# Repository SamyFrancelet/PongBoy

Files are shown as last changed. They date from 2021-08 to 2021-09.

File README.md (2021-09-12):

# PongBoy
 PongBoy is a simple handeld console, made with a 8-bit micro-controller

## Where is the report ?
 The report can be found on 0000_Docs/0004_Report/

## Where is the Schematic and PCB
 Everything Hardware related is located under 0300_Hardware

## Where is the software programmed for this project ?
 The software here is called firmware, and can be found under 0500_Firmware

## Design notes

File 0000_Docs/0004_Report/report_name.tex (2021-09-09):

\documentclass[11pt,titlepage]{report}
\usepackage{Preamble}

\begin{document}

\begin{titlepage}
	\newgeometry{margin=3cm}
	\centering
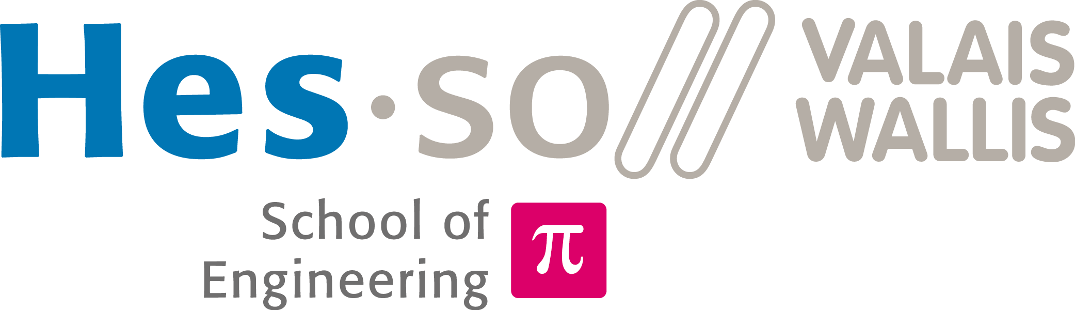
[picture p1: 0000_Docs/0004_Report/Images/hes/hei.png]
    \\[1cm] 	% University Logo
    \textsc{\LARGE Haute école d'ingénieur du Valais}\\ \vspace{\fill}
    \textbf{\textsc{\fontsize{35}{35}\selectfont Report Name}}\\ \vspace{\fill}
	\textsc{\LARGE Course name}\\[0.4cm]
	\rule{\linewidth}{0.2 mm} \\[0.5 cm]
	Author Name \\
	\today
\end{titlepage}
\restoregeometry

\tableofcontents

\chapter{Introduction}
\input{1-Introduction}

\chapter{Méthodes}
\input{2-Methods}

\chapter{Résultats}
\input{3-Results}

\chapter{Discussions}
\input{4-Discussion}

\chapter{Conclusion}
\input{5-Conclusion}

\end{document}

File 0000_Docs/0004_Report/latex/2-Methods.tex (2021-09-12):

\section{Développement Hardware}
L'architecture du Hardware se présente ainsi :
\begin{figure}[H]
  \centering
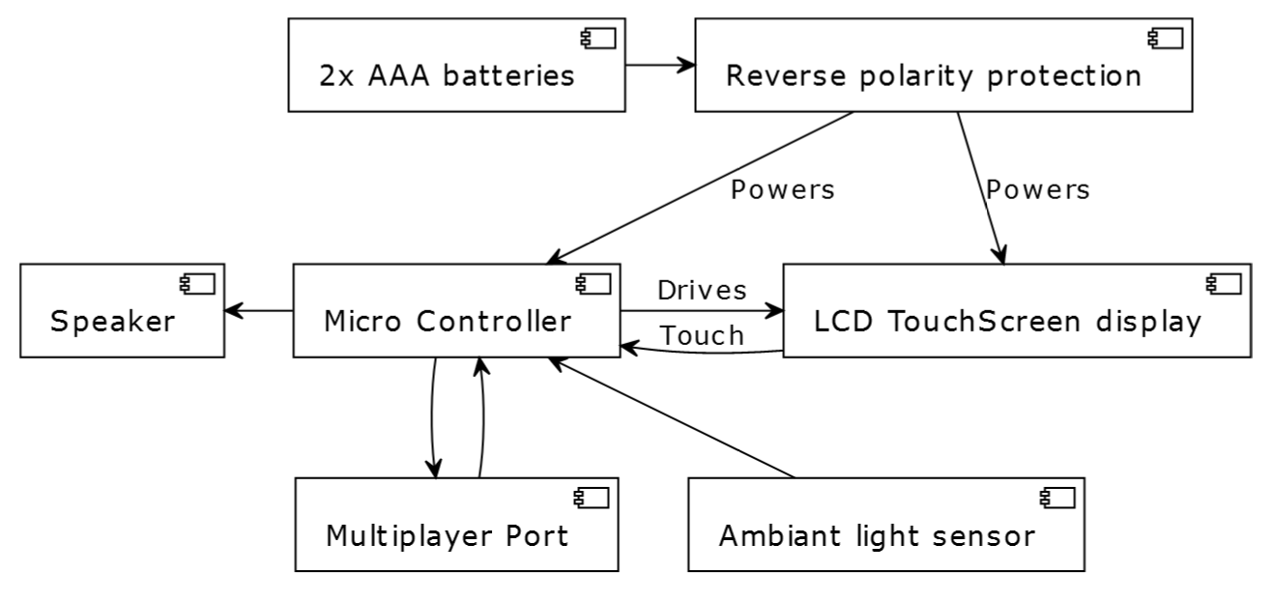
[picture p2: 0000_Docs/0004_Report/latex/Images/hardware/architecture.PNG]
  
  \caption{Architecture hardware de PongBoy}
  \label{hard_arc}
\end{figure}
Le circuit est alimenté par 2 piles AAA, et est protégé contre l'inversion
de polarité. Le micro controlleur commande et récupère des infos de l'écran,
de l'haut-parleur, du capteur de luminosité ambiante, et du port multi-joueur.
\newpage

\subsection{Alimentation}
\begin{figure}[H]
  \centering
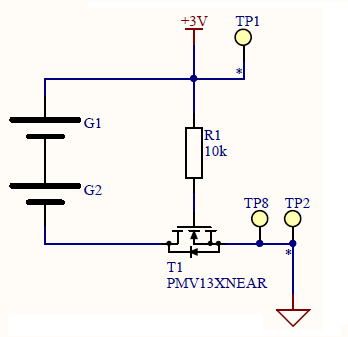
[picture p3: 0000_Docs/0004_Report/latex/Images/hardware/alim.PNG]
  
  \caption{Alimentation avec protection contre polarité inverse}
  \label{hard_pow}
\end{figure}
La protection d'inversion de polarité est un simple N-MOS qui déconnecte
la masse si la tension est inversée. Cette solution est un dérivé de la méthode
bien connue du P-MOS sur le VCC. Le P-MOS est souvent plus cher et moins
efficace que le N-MOS, ce qui est un problème sur notre circuit basse
consommation.
\newpage

\subsection{Micro Controlleur}
\begin{figure}[H]
  \centering
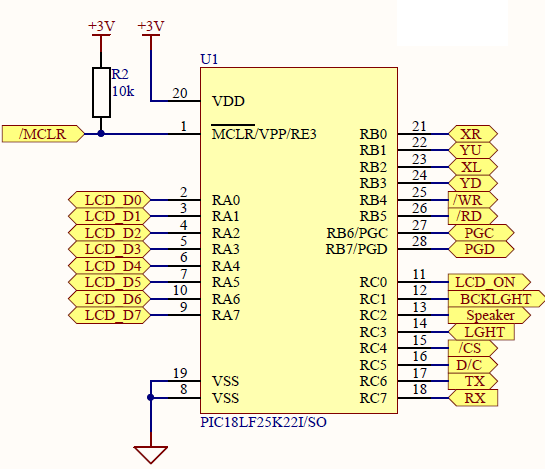
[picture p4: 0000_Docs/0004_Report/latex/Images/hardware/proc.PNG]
  
  \caption{Micro controlleur PIC18LF25K22 avec attribution des GPIO}
  \label{hard_proc}
\end{figure}
Le micro controlleur utilisé est plutôt limité en GPIO, seulement 3 PORT sont
disponibles, mais 3 PORT complet.
Le bus parallèle de l'écran LCD est entièrement attribué au PORTA.
Les 4 résistances de la dalle tactile sont disposée sur le PORTB, sur les pins
0 à 3, choisies pour leur capacités pull-up, d'interruption externe,
et de mesure analogique.
Le contrôle du rétroéclairage (BCKLGHT) est sur un GPIO avec capacité PWM.
PGC, PGD, TX, RX sont préassignée. Le reste n'a pas besoin de capacité
spécifique.

\begin{figure}[H]
  \centering
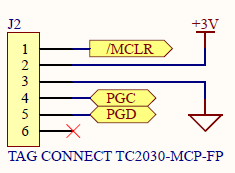
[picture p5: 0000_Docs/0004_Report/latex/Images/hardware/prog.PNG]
  
  \caption{Connecteur de programmation du PIC18LF25K22}
  \label{hard_prog}
\end{figure}
Le connecteur de programmation est un connecteur TagConnect. Le layout
du connecteur est celui du PicKit3.
\newpage

\subsection{Écran résistif tactile LCD}
\begin{figure}[H]
  \centering
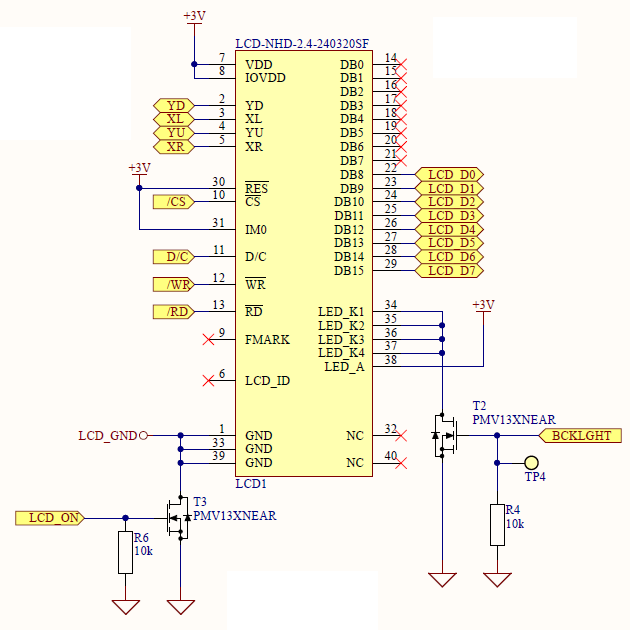
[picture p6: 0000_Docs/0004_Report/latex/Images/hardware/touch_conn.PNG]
  
  \caption{Connecteur de l'écran tacticle LCD}
  \label{hard_lcd}
\end{figure}
Des MOSFET sont présent pour couper l'alimentation de l'écran.
Étant donné que les MOSFET coupent la masse, il faut s'assurer qu'aucune
des pins de l'écran ne soit à la masse lorsqu'on coupe l'alimentation.
Si une pin se retrouve à la masse, un phénomène appelé \emph{Puit de courant}
se produit, et l'écran arrive à s'alimenter avec cette pin.

Pour ce qui est de la détection et mesure de la pression tactile, le principe
suivant sera utilisé sur les pins XR, XL, YU, YD :
\begin{figure}[H]
  \centering
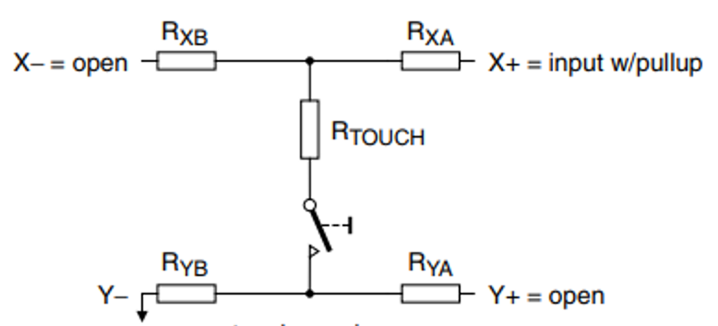
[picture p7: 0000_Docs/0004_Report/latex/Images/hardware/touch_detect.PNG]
  
  \caption{Détection de la pression tactile}
  \label{hard_touchDetect}
\end{figure}
Pour détecter la pression, on se sert de la dalle tactile comme d'un bouton
poussoir, qui va tirer une pin à la masse. Cela requiert donc une pull-up.

\begin{figure}[H]
  \centering
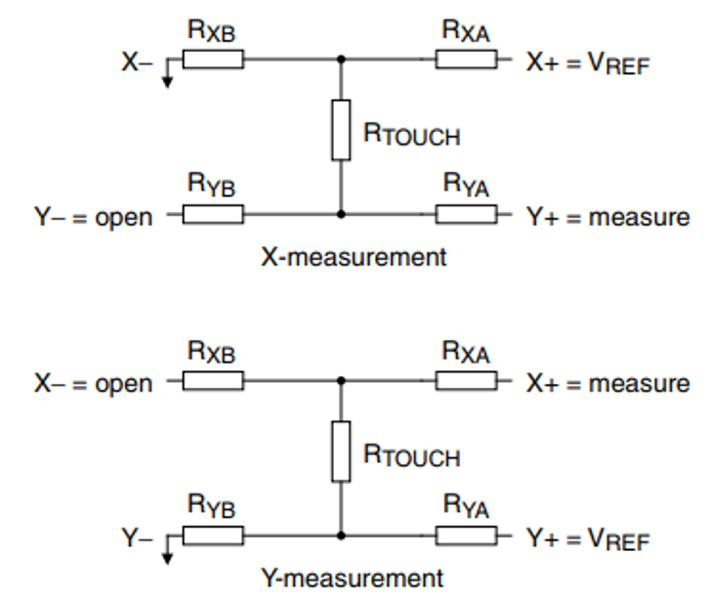
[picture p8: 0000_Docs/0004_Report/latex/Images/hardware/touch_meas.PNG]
  
  \caption{Mesure de la position de la pression tactile}
  \label{hard_touchMeas}
\end{figure}
Pour mesurer la position de la pression, on se sert du pont présent entre
le X et le Y pour faire la mesure. Ainsi, pour mesurer la position en X, nous
mesurons une des pins Y, et trouvons donc la tension du pont-diviseur X.
Et vice-versa pour la position Y.

\subsection{Périphériques}
\subsubsection{Haut-parleur}
\begin{figure}[H]
  \centering
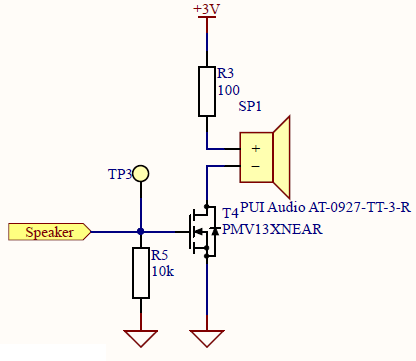
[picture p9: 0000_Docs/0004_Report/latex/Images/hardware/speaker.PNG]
  
  \caption{Haut-parleur avec MOSFET}
  \label{hard_speaker}
\end{figure}
Le haut-parleur est piloté avec un MOSFET, pour éviter de faire passer du
dans le micro controlleur. Il s'agit d'un haut-parleur inductif, il n'est
donc pas nécessaire d'ajouter de diode ou autre composant pour le fonctionnement
lorsque le MOSFET coupe le circuit.

\subsubsection{Capteur de luminosité ambiante}
\begin{figure}[H]
  \centering
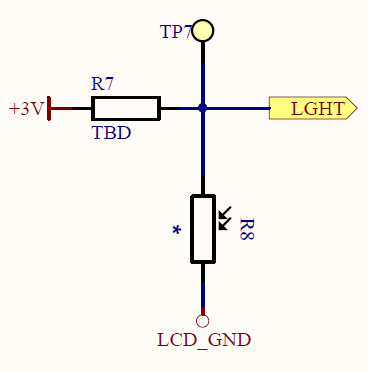
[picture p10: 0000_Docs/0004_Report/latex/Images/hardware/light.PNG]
  
  \caption{Mesure de la lumière ambiante}
  \label{hard_light}
\end{figure}
La mesure de lumière ambiante est réalisée avec une \emph{Light dependant
resistor}. La résistance varie en fonction de la lumière, et cette variation
est mesurée avec un pont-diviseur de tension.
Cette fonctionnalité n'est pour le moment pas du tout implémentée.

\subsubsection{Port multi-joueur}
\begin{figure}[H]
  \centering
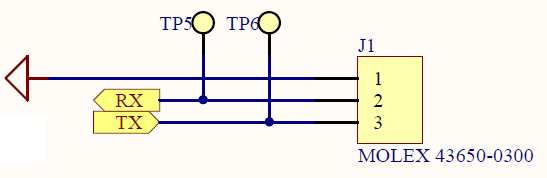
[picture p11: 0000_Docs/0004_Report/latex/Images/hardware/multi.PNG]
  
  \caption{Connecteur de communication pour mode multi-joueur}
  \label{hard_multi}
\end{figure}
Un connecteur 3-MOLEX a été choisi, pour avoir une communication full-duplex,
et transmettre une masse commune.
Cette fonctionnalité n'est pour le moment pas du tout implémentée.
\newpage

\section{Boitier mécanique}
\begin{figure}[H]
  \centering
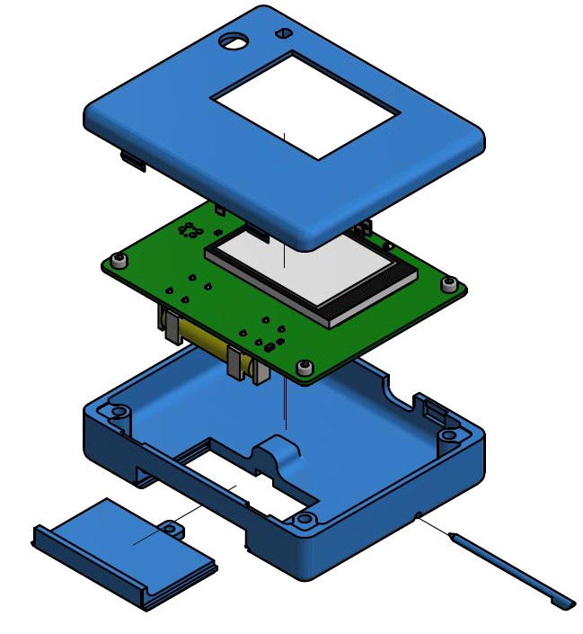
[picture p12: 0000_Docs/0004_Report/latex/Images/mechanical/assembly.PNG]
  
  \caption{Vue éclatée du boîtier complet}
  \label{mech_assembly}
\end{figure}
Le boîtier est composée de deux parties principales : La plaque inférieur,
surlaquelle le circuit imprimé viens se fixer. Et la plaque supérieur, qui
se \emph{clips} sur la plaque inférieur.
Le circuit imprimé est fixé à l'aide de vis M3, et d'inserts filtés.

Un point d'accès aux piles est présent, pour faciliter le changement de piles.
Un stylet a été pensé, pour éviter que l'utilisation du doigt pour le tactile
ne bloque la visibilité de l'écran. Il permet également une utilisation plus
précise du tactile. Le stylet est inspiré de celui d'une \emph{Nintendo DS}.
\begin{figure}[H]
  \centering
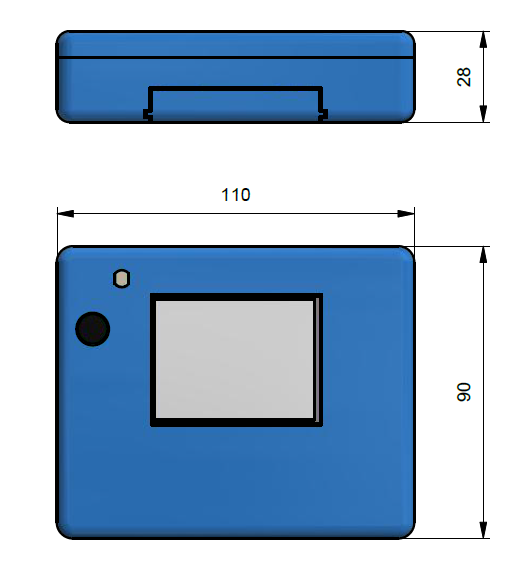
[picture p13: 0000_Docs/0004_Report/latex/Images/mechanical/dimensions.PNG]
  
  \caption{Dimensions d'encombrement du bôitier}
  \label{mech_dimensions}
\end{figure}
\newpage

\section{Développement Firmware}
\begin{figure}[H]
  \centering
  
  \caption{Architecture firmware}
  \label{firm_arc}
\end{figure}
Le firmware est découpé en plusieurs modules s'occupant chacun d'un élément
ou d'une partie du PongBoy spécifique :
\begin{itemize}
  \item le LCD driver s'occupe d'afficher sur l'écran, et de gérer le
  rétroéclairage
  \item TouchScreen s'occupe de détecter une pression sur l'écran, et
  de mesurer la position de cette pression pour la transmettre plus loin
  \item Display s'occupe de rafraîchir l'affichage toutes les $30ms$, il
  est informé des changement de menu vers sous-menu, ou vers le jeu
  \item PongBoy controller est une \emph{Factory}, il contient simplement
  tous les controlleurs de la console, comme Display ou Game Controller.
  Il s'occupe également de la mise en veille de la console.
  \item Menu Controller et Game Controller font le lien entre les
  commandes de l'utilisateur, et le menu ou jeu correspondant
  \item Les \emph{GameObjects} Ball et Paddle sont les balles et
  raquette du jeu Pong
\end{itemize}

Le liens entre tout ces modules est le gestionnaire d'évenement XF.
Chaque module peut envoyer un évenement dans la file d'attente de XF, ou
programmer un timer qui transmettera un évenement.
Cette file d'attente est vidée progressivement, et les évenements qui en sortent
sont retransmis à tous les modules, qui modifieront leur comportement selon
l'évenement. Un exemple simple : Le jeu se ferme lorsqu'il reçoit l'évenement
GameOver.

\subsection{TouchScreen}
\begin{figure}[H]
  \centering
  
  \caption{Diagramme d'activité du TouchScreen}
  \label{firm_touch}
\end{figure}
La détection de la pression et la méthode de mesure est détaillée au
point 2.1.3.
Le TouchScreen ne mesure que quand une pression est détectée. Les mesures
sont espacées entre elles à l'aide d'un timer.
À la fin de chaque conversion, le TouchScreen envoie un évenement signalant
une nouvelle mesure.
L'interruption externe du tactile permet de transmettre des évenement
\emph{Press} et \emph{Release}.
\newpage

\subsection{Mise en veille}
\begin{figure}[H]
  \centering
  
  \caption{Diagramme d'activité du PongBoy - fonction veille}
  \label{firm_sleep}
\end{figure}
La mise en veille est gérée avec un timer de XF de $20s$. À chaque
appui sur l'écran tactile, le timer est supprimé et un nouveau est relancé.
\newpage

\subsection{Contrôleurs}
\subsubsection{Pong Controller}
\begin{figure}[H]
  \centering
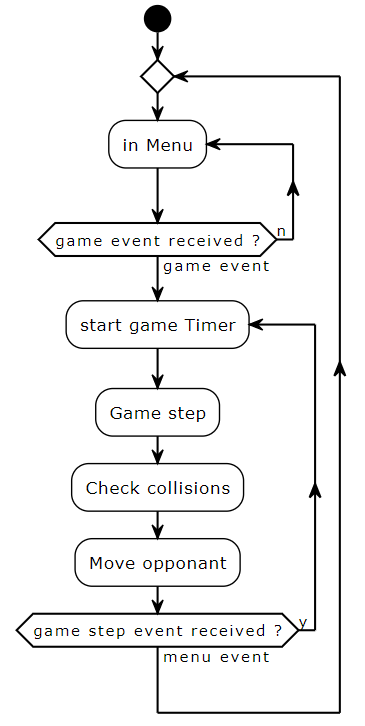
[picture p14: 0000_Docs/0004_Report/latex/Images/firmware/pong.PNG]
  
  \caption{Diagramme d'activité du Pong Controller}
  \label{firm_pong}
\end{figure}
Le contrôleur de jeu différencie deux états, en jeu et dans le menu.
Lorsqu'on est dans le menu, le jeu ne fais rien.
Lorsqu'on est en jeu, un timer est lancé pour gérer la physique du jeu.
L'affichage du jeu est découplé de ce contrôleur, l'afficheur sait simplement
qu'on est en jeu, et il affiche les objets du jeux sur l'écran toutes les $30ms$.

\subsubsection{Menu Controller}
Le contrôleur de menu fonctionne de manière similaire au pong, sans la partie
jeu. Il comprend des états de sous-menu.
\newpage

\subsection{Paddle}
\begin{figure}[H]
  \centering
  
  \caption{Diagramme d'activité du Paddle}
  \label{firm_paddle}
\end{figure}
La gestion du mouvement du Paddle joueur est découplée du contrôleur de jeu.
Le contrôleur de jeu transmet les évenements au Paddle.
Si une pression sur l'écran a été détectée, le Paddle va checker si la pression
est sur la partie du haut ou du bas de l'écran, et va modifier sa vitesse
en adéquation.

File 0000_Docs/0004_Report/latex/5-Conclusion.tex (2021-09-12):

\section{Bilan}
Le cahier des charges a été respecté dans son intégralité. Le mode veille
fonctionne consomme $9[\mu A]$.
Le gameplay est proche du vrai Pong, l'utilisation du stylet rend le gameplay
plus agréable qu'au doigt.
Le réglage du rétroéclairage fonctionne parfaitement, et permet aussi meilleure
autonomie.

\section{Points à corriger}
\begin{itemize}
  \item Sur le PCB v1.0, les signaux PGC et PGD ont été inversés sur le port
  de programmation.
  \item Sur le PCB v1.0 Les connecteurs de piles sont trop proches l'un de l'autre, du scotch.
  isolant a dû être placé pour éviter des courts-circuits.
  \item Sur le boîtier v2.1, les fixations de la plaque supérieur sont trop
  fragiles.
  \item Sur le boîtier v2.1, l'accès aux piles est trop étroit et rend
  le changement de pile avec les doigts très désagréable.
  \item Sur le boîtier v2.1, le stylet ne peut pas rentrer correctement dans
  le boîtier à cause de l'impression 3D imprécise.
  \item Les pull-downs présentent sur les Gate des MOSFET ne sont pas
  nécessaires. Le PIC18LF25K22, lorsqu'il part en veille, concerve
  l'état de ses entrées/sorties d'avant veille.
\end{itemize}

\section{Voies d'amélioration}
\begin{itemize}
  \item Ajout d'un joystick ou slider pour le contrôle du Paddle.
  \item Amélioration du menu du PongBoy, ajout d'informations visuelles pour
  l'utilisateur (par ex: le slider de luminosité n'a pas de légende).
  \item Ajout de plusieurs réglages dans le menu paramètres (par ex: choisir
  de jouer sur fond blanc plutôt que fond noir).
  \item Amélioration du gameplay (balle qui s'accélère durant la manche).
  \item Ajout d'un choix de difficulté de l'adversaire dans Pong.
  \item Implémentation du haut-parleur, ajout de feedback sonore dans le menu
  et dans le Pong.
  \item Implémentation du capteur de luminosité ambiante, et réglage automatique
  du rétroéclairage.
  \item Implémentation du mode multi-joueur.
\end{itemize}

\section{Signatures}
Samy Francelet

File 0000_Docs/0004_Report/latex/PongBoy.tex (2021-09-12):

\documentclass[11pt,titlepage]{report}
\usepackage{Preamble}

\begin{document}

\begin{titlepage}
	\newgeometry{margin=3cm}
	\centering
    \\[1cm] 	% University Logo
    \textsc{\LARGE Haute école d'ingénieur du Valais}\\ \vspace{\fill}
    \textbf{\textsc{\fontsize{35}{35}\selectfont PongBoy}}\\ \vspace{\fill}
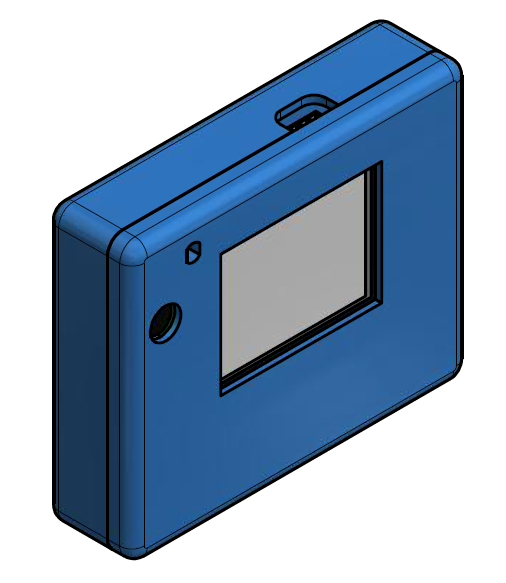
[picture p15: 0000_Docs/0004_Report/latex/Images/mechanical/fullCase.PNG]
		\\[2cm]
	\textsc{\LARGE Summer School 2}\\[0.4cm]
	\rule{\linewidth}{0.2 mm} \\[0.5 cm]
	Samy Francelet \\
	\today
\end{titlepage}
\restoregeometry

\tableofcontents

\chapter{Introduction}
\input{1-Introduction}

\chapter{Conception}
\input{2-Methods}

\chapter{Résultats et tests}
\input{3-Results}

%\chapter{Discussions}
%\input{4-Discussion}

\chapter{Conclusion}
\input{5-Conclusion}

\appendix
\chapter{Protocoles de test}
\includepdf[pages=-]{files/Test_protocols.pdf}

\end{document}

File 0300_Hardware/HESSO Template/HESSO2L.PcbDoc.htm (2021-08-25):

Reporting Options

# File in Previous Format

Date | : | 25.08.2021
Time | : | 13:53:03
Filename | : | C:\Users\samy.francele\Documents\PongBoy\0300_Hardware\HESSO Template\HESSO2L.PcbDoc

Version | Warning

This file was generated by an earlier version of the software

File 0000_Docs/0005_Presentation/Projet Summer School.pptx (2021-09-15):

## Projet Summer School PongBoy

Samy Francelet

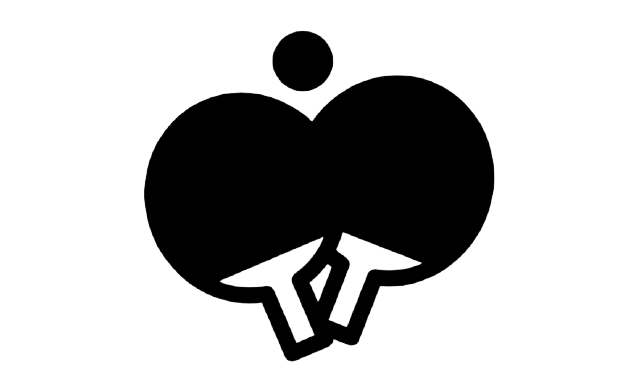
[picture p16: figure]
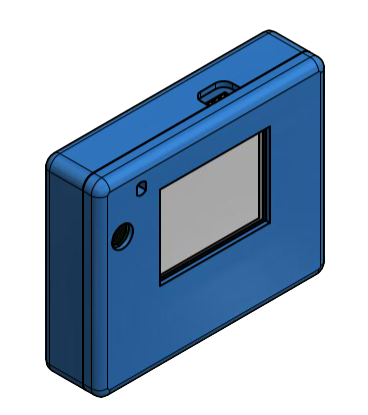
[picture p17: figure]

## Sommaire

Cahier des charges
Hardware
Mécanique
Firmware
Résultats
Bilan

## Cahier des charges

Basse consommation
Pile AAA
Écran tactile résistif
Pas de puce driver
Processeur : PIC18LF25K22
Nombre de GPIO limité
Console de jeu portable Pong
8 bits
Possibilités de calcul limitées
Basse consommation
3 semaines

## Hardware

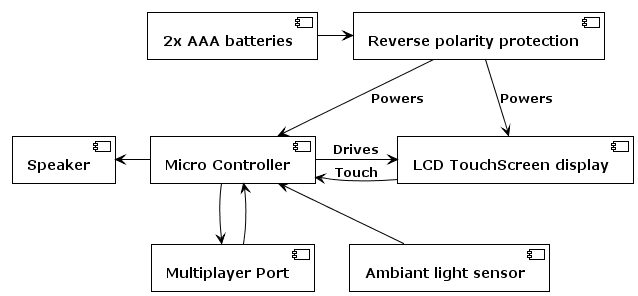
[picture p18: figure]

## Mécanique

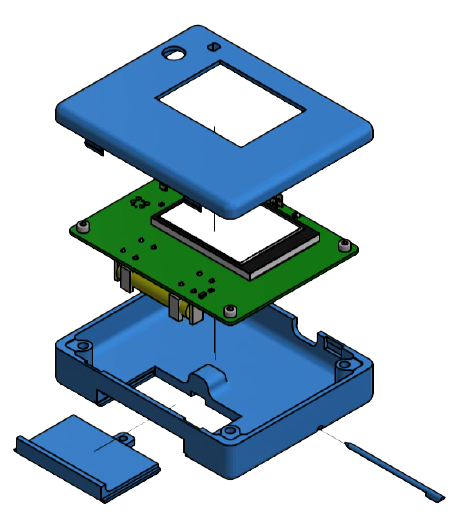
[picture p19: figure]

## Structure du Firmware

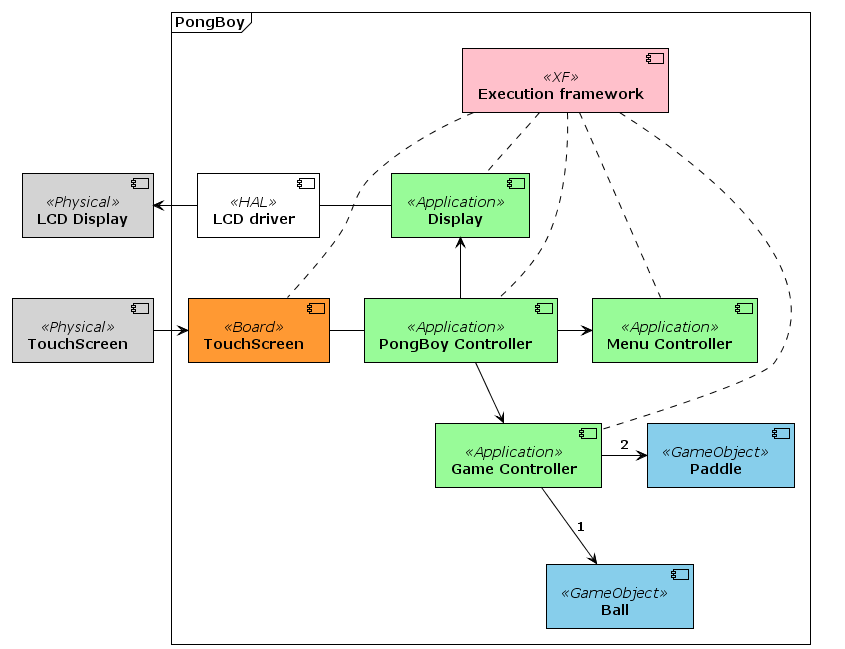
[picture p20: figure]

## Lecture du TouchScreen

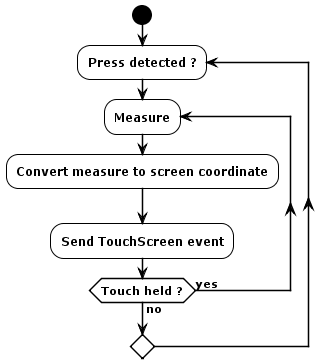
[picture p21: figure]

## Gestion de l’alimentation

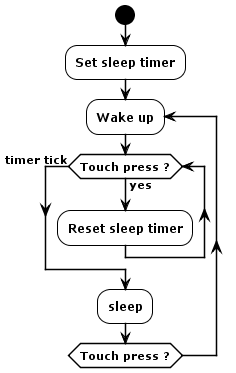
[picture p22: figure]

## Controlleur de jeu

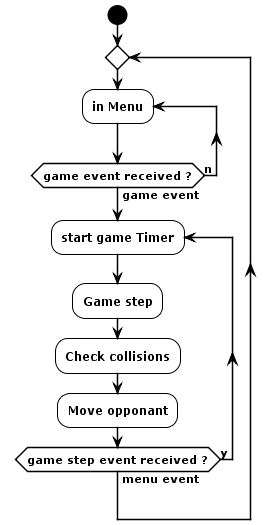
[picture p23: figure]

## Control du Paddle

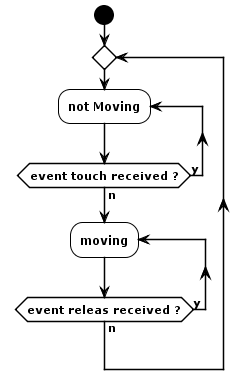
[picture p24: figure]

## Résultats

- Protection de l’inversion de polarité des piles
- Gestion de l’énergie fonctionnelle
- Gestion du rétroéclairage fonctionnelle
- Code réutilisable

## Résultats


## Bilan

Corrections :
Schématique et circuit imprimé
Voie d’améliorations :
Niveaux de difficulté
Joystick ou slider pour le contrôle
Haut-parleur
Détection de la lumière ambiante
Mode multijoueur
Accès des piles plus large
Cahier des charges respecté
Game Over
Menu plus complet
Fixation de la plaque du dessus plus solide

## Questions


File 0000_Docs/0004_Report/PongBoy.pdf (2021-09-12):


### HAUTE ÉCOLE D’INGÉNIEUR DU VALAIS

# PONGBOY


### SUMMER SCHOOL 2

Samy Francelet
12 septembre 2021

# Table des matières

1 Introduction | 2
2 Conception | 3
3 Résultats et tests | 15
4 Conclusion | 17
A Protocoles de test | 18

# Chapitre 1

# Introduction

## 1.1 Contexte

Ce projet a été réalisé dans le cadre du cours Summer School 2 - Infotronic de la Haute école d’ingénieur du Valais. Ce cours de 3 semaines se passe à la fin de l’été, avant la reprise de septembre. Il a pour but de mettre en pratique les compétences acquises durant la 2e année du bachelor. L’objectif du projet est de développer une console de jeu portable, avec écran tactile, permettant de jouer au jeu Pong.
Normalement, des équipes de 2 personnes sont formées, mais dû au fait que nous sommes un nombre impaire, je me suis retrouvé à développer le PongBoy seul.

## 1.2 Spécifications

— La console doit être alimentée par 2 piles AAA en série, et ainsi fonctionner en 3[V ].
— Une protection contre l’inversion de polarité des piles doit être présente.
— La console doit pouvoir être mise en veille ultra-basse-consommation, pour éviter de changer les piles AAA trop régulièrement.
— L’écran tactile résistif NHD-2.4-240320SF-CTXL-FTN1 doit être utilisé, et une interface tactile doit être implémentée.
— L’utilisation d’une puce driver pour l’écran tactile est prohibée, une librairie driver est fournie. — Le micro-controlleur PIC18LF25K22 doit être utilisé, au format SOIC, pour ses capacités d’ultrabasse-consommation.
— L’alimentation de l’écran LCD ainsi que de son rétro-éclairage doit pouvoir être coupée pour respecter la contrainte d’ultra-basse-consommation.

# Chapitre 2

# Conception

## 2.1 Développement Hardware

L’architecture du Hardware se présente ainsi :


FIGURE 2.1 – Architecture hardware de PongBoy

Le circuit est alimenté par 2 piles AAA, et est protégé contre l’inversion de polarité. Le micro controlleur commande et récupère des infos de l’écran, de l’haut-parleur, du capteur de luminosité ambiante, et du port multi-joueur.

Conception | PongBoy - Summer School 2

### 2.1.1 Alimentation


FIGURE 2.2 – Alimentation avec protection contre polarité inverse

La protection d’inversion de polarité est un simple N-MOS qui déconnecte la masse si la tension est inversée. Cette solution est un dérivé de la méthode bien connue du P-MOS sur le VCC. Le P-MOS est souvent plus cher et moins efficace que le N-MOS, ce qui est un problème sur notre circuit basse consommation.

### 2.1.2 Micro Controlleur


FIGURE 2.3 – Micro controlleur PIC18LF25K22 avec attribution des GPIO

Le micro controlleur utilisé est plutôt limité en GPIO, seulement 3 PORT sont disponibles, mais 3 PORT complet. Le bus parallèle de l’écran LCD est entièrement attribué au PORTA. Les 4 résistances de la dalle tactile sont disposée sur le PORTB, sur les pins 0 à 3, choisies pour leur capacités pull-up, d’interruption externe, et de mesure analogique. Le contrôle du rétroéclairage (BCKLGHT) est sur un GPIO avec capacité PWM. PGC, PGD, TX, RX sont préassignée. Le reste n’a pas besoin de capacité spécifique.


FIGURE 2.4 – Connecteur de programmation du PIC18LF25K22

Le connecteur de programmation est un connecteur TagConnect. Le layout du connecteur est celui du PicKit3.

### 2.1.3 Écran résistif tactile LCD


FIGURE 2.5 – Connecteur de l’écran tacticle LCD

Des MOSFET sont présent pour couper l’alimentation de l’écran. Étant donné que les MOSFET coupent la masse, il faut s’assurer qu’aucune des pins de l’écran ne soit à la masse lorsqu’on coupe l’alimentation. Si une pin se retrouve à la masse, un phénomène appelé Puit de courant se produit, et l’écran arrive à s’alimenter avec cette pin.
Pour ce qui est de la détection et mesure de la pression tactile, le principe suivant sera utilisé sur les pins XR, XL, YU, YD :


FIGURE 2.6 – Détection de la pression tactile

Pour détecter la pression, on se sert de la dalle tactile comme d’un bouton poussoir, qui va tirer une pin à la masse. Cela requiert donc une pull-up.


FIGURE 2.7 – Mesure de la position de la pression tactile

Pour mesurer la position de la pression, on se sert du pont présent entre le X et le Y pour faire la mesure. Ainsi, pour mesurer la position en X, nous mesurons une des pins Y, et trouvons donc la tension du pont-diviseur X. Et vice-versa pour la position Y.

### 2.1.4 Périphériques

Haut-parleur


FIGURE 2.8 – Haut-parleur avec MOSFET

Le haut-parleur est piloté avec un MOSFET, pour éviter de faire passer du dans le micro controlleur. Il s’agit d’un haut-parleur inductif, il n’est donc pas nécessaire d’ajouter de diode ou autre composant pour le fonctionnement lorsque le MOSFET coupe le circuit.

Capteur de luminosité ambiante


FIGURE 2.9 – Mesure de la lumière ambiante

La mesure de lumière ambiante est réalisée avec une Light dependant resistor. La résistance varie en fonction de la lumière, et cette variation est mesurée avec un pont-diviseur de tension. Cette fonctionnalité n’est pour le moment pas du tout implémentée.

Port multi-joueur


FIGURE 2.10 – Connecteur de communication pour mode multi-joueur

Un connecteur 3-MOLEX a été choisi, pour avoir une communication full-duplex, et transmettre une masse commune. Cette fonctionnalité n’est pour le moment pas du tout implémentée.

## 2.2 Boitier mécanique


FIGURE 2.11 – Vue éclatée du boîtier complet

Le boîtier est composée de deux parties principales : La plaque inférieur, surlaquelle le circuit imprimé viens se fixer. Et la plaque supérieur, qui se clips sur la plaque inférieur. Le circuit imprimé est fixé à l’aide de vis M3, et d’inserts filtés.
Un point d’accès aux piles est présent, pour faciliter le changement de piles. Un stylet a été pensé, pour éviter que l’utilisation du doigt pour le tactile ne bloque la visibilité de l’écran. Il permet également une utilisation plus précise du tactile. Le stylet est inspiré de celui d’une Nintendo DS.


FIGURE 2.12 – Dimensions d’encombrement du bôitier

## 2.3 Développement Firmware


FIGURE 2.13 – Architecture firmware

Le firmware est découpé en plusieurs modules s’occupant chacun d’un élément ou d’une partie du PongBoy spécifique :
— le LCD driver s’occupe d’afficher sur l’écran, et de gérer le rétroéclairage
— TouchScreen s’occupe de détecter une pression sur l’écran, et de mesurer la position de cette pression pour la transmettre plus loin
— Display s’occupe de rafraîchir l’affichage toutes les 30ms, il est informé des changement de menu vers sous-menu, ou vers le jeu
— PongBoy controller est une Factory, il contient simplement tous les controlleurs de la console, comme Display ou Game Controller. Il s’occupe également de la mise en veille de la console. — Menu Controller et Game Controller font le lien entre les commandes de l’utilisateur, et le menu ou jeu correspondant
— Les GameObjects Ball et Paddle sont les balles et raquette du jeu Pong
Le liens entre tout ces modules est le gestionnaire d’évenement XF. Chaque module peut envoyer un évenement dans la file d’attente de XF, ou programmer un timer qui transmettera un évenement. Cette file d’attente est vidée progressivement, et les évenements qui en sortent sont retransmis à tous les modules, qui modifieront leur comportement selon l’évenement. Un exemple simple : Le jeu se ferme lorsqu’il reçoit l’évenement GameOver.

### 2.3.1 TouchScreen


FIGURE 2.14 – Diagramme d’activité du TouchScreen

La détection de la pression et la méthode de mesure est détaillée au point 2.1.3. Le TouchScreen ne mesure que quand une pression est détectée. Les mesures sont espacées entre elles à l’aide d’un timer. À la fin de chaque conversion, le TouchScreen envoie un évenement signalant une nouvelle mesure. L’interruption externe du tactile permet de transmettre des évenement Press et Release.

### 2.3.2 Mise en veille


FIGURE 2.15 – Diagramme d’activité du PongBoy - fonction veille

La mise en veille est gérée avec un timer de XF de 20s. À chaque appui sur l’écran tactile, le timer est supprimé et un nouveau est relancé.

### 2.3.3 Contrôleurs

Pong Controller


FIGURE 2.16 – Diagramme d’activité du Pong Controller

Le contrôleur de jeu différencie deux états, en jeu et dans le menu. Lorsqu’on est dans le menu, le jeu ne fais rien. Lorsqu’on est en jeu, un timer est lancé pour gérer la physique du jeu. L’affichage du jeu est découplé de ce contrôleur, l’afficheur sait simplement qu’on est en jeu, et il affiche les objets du jeux sur l’écran toutes les 30ms.

Menu Controller

Le contrôleur de menu fonctionne de manière similaire au pong, sans la partie jeu. Il comprend des états de sous-menu.

### 2.3.4 Paddle


FIGURE 2.17 – Diagramme d’activité du Paddle

La gestion du mouvement du Paddle joueur est découplée du contrôleur de jeu. Le contrôleur de jeu transmet les évenements au Paddle. Si une pression sur l’écran a été détectée, le Paddle va checker si la pression est sur la partie du haut ou du bas de l’écran, et va modifier sa vitesse en adéquation.

# Chapitre 3

# Résultats et tests

## 3.1 Résultats


FIGURE 3.1 – Boîtier complet du PongBoy

Le cahier des charges est respecté. La jouabilité est correcte. Par manque de temps, et manque de ressources humaines, les fonctionnalités comme le haut-parleur, et le mode multi-joueur n’ont pas pu être implémentés.

Résultats et tests | PongBoy - Summer School 2

## 3.2 Test

De nombreux tests ont été réalisés pour vérifier la qualité du produit. Ces tests ont permis de détecter de nombreux problèmes, qui ont bien entendu été corrigés.


FIGURE 3.2 – Signaux de programmation PGC et PGD inversés

Par exemple, les signaux PGC et PGD du port de programmation ont été inversé dans la schématique, résultant en une impossibilité de programmer le processeur. Cela a été corrigé comme montré dans la figure 3.2
L’ensemble des tests réalisés durant ce projet sont disponibles en Annexe A.

# Chapitre 4

# Conclusion

## 4.1 Bilan

Le cahier des charges a été respecté dans son intégralité. Le mode veille fonctionne consomme 9[µA]. Le gameplay est proche du vrai Pong, l’utilisation du stylet rend le gameplay plus agréable qu’au doigt. Le réglage du rétroéclairage fonctionne parfaitement, et permet aussi meilleure autonomie.

## 4.2 Points à corriger

— Sur le PCB v1.0, les signaux PGC et PGD ont été inversés sur le port de programmation.
— Sur le PCB v1.0 Les connecteurs de piles sont trop proches l’un de l’autre, du scotch. isolant a dû être placé pour éviter des courts-circuits.
— Sur le boîtier v2.1, les fixations de la plaque supérieur sont trop fragiles.
— Sur le boîtier v2.1, l’accès aux piles est trop étroit et rend le changement de pile avec les doigts très désagréable.
— Sur le boîtier v2.1, le stylet ne peut pas rentrer correctement dans le boîtier à cause de l’impression 3D imprécise.
— Les pull-downs présentent sur les Gate des MOSFET ne sont pas nécessaires. Le PIC18LF25K22, lorsqu’il part en veille, concerve l’état de ses entrées/sorties d’avant veille.

## 4.3 Voies d’amélioration

— Ajout d’un joystick ou slider pour le contrôle du Paddle.
— Amélioration du menu du PongBoy, ajout d’informations visuelles pour l’utilisateur (par ex : le slider de luminosité n’a pas de légende).
— Ajout de plusieurs réglages dans le menu paramètres (par ex : choisir de jouer sur fond blanc plutôt que fond noir).
— Amélioration du gameplay (balle qui s’accélère durant la manche).
— Ajout d’un choix de difficulté de l’adversaire dans Pong.
— Implémentation du haut-parleur, ajout de feedback sonore dans le menu et dans le Pong.
— Implémentation du capteur de luminosité ambiante, et réglage automatique du rétroéclairage. — Implémentation du mode multi-joueur.

## 4.4 Signatures

Samy Francelet

# Annexe A

# Protocoles de test

Test ID | Hardware - 01
Description | Inspection des défauts de fabrication
Pattern | White Box
Test Description | Le PCB, juste après la fabrication et l'usinage, est inspecté à la loupe dans le but de rechercher d'éventuelle court circuit entre les pistes ou alors des pistes coupées qui aurait été rongée par l'acide
Personnel | Samy Francelet
Results | 2 pistes coupées : PGC et PGD
Conclusions | Le cuivre de la face supérieur a été plus mangé par l'acide, les pistes fines du port de programmation en ont souffert
Measures | Un morceau de fil conducteur a été soudé par-dessus la piste
Test ID | Hardware - 02
Description | Ce test permet de vérifier si le PCB n'a pas de court-circuit
Pattern | Smoke test
Test Description | Le PCB assemblé complet va être inspecté à la loupe, puis alimenté en 3V, avec une limitation de courant <150mA pour éviter de faire de trop gros dégats en cas de court-circuit.
Personnel | Samy Francelet
Results | Pas de court-circuit observé. Le courant est <10mA.
Conclusions | Ce courant correspond à la consommation du PIC n'étant pas encore programmé.
Measures | Le test est réussi.
Test ID | Hardware - 03
Description | Ce test permet de vérifier la protection contre l'inversion de polarité
Pattern | Smoke test
Test Description | On inverse la polarité de l'alimentation afin de voir si notre protection fonctionne correctement
Personnel | Samy Francelet
Results | Pas d'échauffement de composant. Pas de courant
Conclusions | La protection d'alimentation fonctionne correctement
Measures | Le test est réussi.

Test ID | Firmware - 01
Description | Programmabilité du micro contrôleur
Pattern | White Box
Test Description | On lance MPLAB puis on crée un nouveau projet avec le bon compilateur (XC8) et le bon PIC (18LF25k22). Le PCB vient se connecter avec le connecteur de programmation sur l'ordinateur. Une première compilation et programmation est lancée. Si le programme s'arrête avec une erreur, on débranche le Pickit3 et on cherche la faute. Sinon, le test prend fin.
Personnel | Samy Francelet
Results | MPLAB ne reconnait pas le micro contrôleur
Conclusions | Les pins PGC et PGD sont inversées
Measures | Les deux pistes sont coupées et deux fils sont utilisés à la place
Test ID | Firmware - 02
Description | Changement de couleur de fond d'écran
Pattern | White Box
Test Description | Vérifie que la commande tactile fonctionne, et que la communicaiton avec l'écran fonctionne
Personnel | Samy Francelet
Results | Fonctionnel
Conclusions | Le test est reussi

Measures

Test ID | Firmware - 03
Description | Balle qui rebondit contre les parois de l'écran
Pattern | White Box
Test Description | Vérifie que le contrôleur de jeu fonctionne et que les collisions sont correctes
Personnel | Samy Francelet
Results | Aucun bug de rebond
Conclusions | Le test est réussi
Measures
Test ID | Firmware - 04
Description | Test du sleep
Pattern | White Box
turn | On vérifie que l'appereil s'éteint belle et bien après 20 sec
Personnel | Samy Francelet
Results | L'appareil s'éteint correctement
Conclusions | Le test est réussi
Measures
Test ID | Firmware - 05
Description | Stress test du jeu Pong
Pattern | Black box
Test Description | Vérifier que le programme répond correctement, même si plusieurs utilisateurs viennent essayer le jeu, faire des commandes absurdes, appuyer avec 12 doigts, etc..
Personnel | Samy Francelet
Results | Aucun bug détecté
Conclusions | Le test est réussi
Measures

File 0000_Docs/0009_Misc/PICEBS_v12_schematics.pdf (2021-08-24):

1 | I | 2 | I | 3 | I | 4 | I | 5 | 6 | I | 7 | I | 8 | 9 | I | 10
A | A
t-- | -

# Table of contents

Page number | Title | Details B | B
1 | TOC | THIS PAGE
2 | Revision | REVISION HISTORY, GLABAL TOLEANCE
3 | USB INTERFACE
4 | Power | 3-STATE VDD_ GND, COMMAND TARGET POWER, VOLTAGE REFERECES, POWER MESURE

t--

| | | DRIVER CHIPSET POWER, 3-STATE (LVP,CLK, DAT), +5V _ USB ORDER | -
C | 5 | CPU PICKIT | PIC24FJ256GB106, SERIAL EEPROM | C
| 6 | CONNECTOR | Switching system
t-- | 7 | POWER PICEBS2 | LP3965EM-33 | -
| 8 | CPU PICEBS2 | PIC18F87K22, CONNECTOR PROGRAMATION PICEBS2
D | 9 | TOUCH DISPLAY | DIRVER: STMPEB 11, LCD: LCD-NHD-1.8-128160EF | D
| 10 | 1/0 | BUTTON: INT0,INT1, KBl0. POTENTIONMETER. Olimex UEXT, CONNECTORS
11 | INTERFACE | LED BAR. RS232 DRIVER: MAX3221 CAE. MODULE CAN: MCP2515, SN65HVD231 DR. t-- | -
E | E
t-- | -
F | PICEBS2 | DES | 28.05.2015 SNGB | F

### Microchip dev. board TOC

REV | V1.2
HAUTE ECOLE VALAISANNE | 1/11 | {Path! PICEBS2 V1 .2.sch
1 | I | 2 | I | 3 | I | 4 | I | 5 | 6 | I | 7 | I | 8 | 9 | I | 10

1 | I | 2 | I | 3 | I | 4 | I | 5 | 6 | I | 7 | I | 8 | 9 | I | 10
Revision history A | A
Revision | Major changes

## 1.0 First prototype board

t-- | 1. 1 | Never build | -

## 1.2 First serie board

B | B

# Build info t--

Resistor tolerance: 1 X unless otherwise noted | -
C | C
t-- | -
D | D
t-- | -
E | E
t-- | -
F | PICEBS2 | DES | 28.05.2015 SNGB | F

### Microchip dev. board REVISION

REV | V1.2
HAUTE ECOLE VALAISANNE | 2/11 | {Path! PICEBS2 V1 .2.sch
1 | I | 2 | I | 3 | I | 4 | I | 5 | 6 | I | 7 | I | 8 | 9 | I | 10

2 | 3 | 4 | 5 | 6 | 7 | 8 | 9 | 10
DRIVER CHIPSET POWER | +5V USB COMMAND

A A
ZXTP25020CFH | F1 FUSE REARMABLE D1 | Q1 VBUS_PI< USB INTERFACE | * VBUS_DEVICE)
500mA ⁽BUS POWERD) | MBR0520L | l+3.3V_PKI | D R1
J1 | U1 | 10k
VBUS_PK | 8
2 | 2 | 7 | 7 | LD1
~ GREEN _LC1 | 3 | 3 | 6 T2.2u | R3 | C2 | R4 4 | 5 | 5 | 330 | 47p | 2.2k | l+sv_use_oooo) 4 | _LC3 | C4 | _LC5
MCP1727 | R5 | T100n | 2.2u T 10n D R6 | R7 B | B
~ | 200k | 2.2k | 390
0 | R10 | Q2 | R9 +sv_use_oN) | c::::::J . | 2k 1X /

2.2k
DR11
10k

## 3-STATE FOR LVP

•'-l"I U2 | lvoo_ rARI C | R12 | C 1 VCCA VCCB 6 | (LVP_VDD) | c::::::J 5 DIR | 100 | F2 FUSE REARMABLE
3 A | B 4 | 3-STATE FOR DAT
330 | 2 GND | 50mA R14 | D2 | U3 74LVC1T45 | 4.7k | 3SMAJ5918B-TP
5 DIR | 100 | F3 FUSE REARMABLE
3A | B4 | ICSP _DAT) LVP _ VDD
Tes l·1:7 | 2 GND | 50mA | D D | DR17 | D3 74LVC1T45 I100n | I100n | 4.7k | 3SMAJ5918B-TP

330

# / i~r~8 Tcg

3-STATE FOR CLK | I100n | I100n
U4 | R19 | lvoo_ rARI E | E

VCCB 6
~ | 5 DIR | 100 | F4 FUSE REARMABLE R20 | 3 A | B 4
330 | 2 GND | 50mA R21 | D4 74LVC1T45 | 4.7k | 3SMAJ5918B-TP
lcLOCK_VDD | l·r~¹
11 | PICEBS2 | DES | 28.05.2015 SNGB F | _LC10 | F
T100n | I100n | Microchip dev. board | USB Interface PICkit | REV | V1.2
HAUTE ECOLE VALAISANNE | 3/11 | {Path! / | PICEBS2 V1 .2.sch - 2 | 3 | 4 | 5 | 6 | 7 | 8 | 9 | 10

A

B


C

D

2 | 3 | 4 | 5 | 7 | 8 | 10
COMMAND TARGET POWER | POWER MESURE

R26
c:::::J
10k

D R24
10k | _LC14
| T100n
4 | "' U5 1 +vs | 1,,-


3 + -: MCP601
C16 DR30
1100n ,,- 10k ,,-

## VOLTAGE REFERENCES

2 | 3 | 4
R23 | C12 ..±L_C13 .- L1
"' | D5
10kI100nT10u | 680uH
~-----~--~--~----- / | BAT54 | DR27
Q5 | 10k
R31
~MMBT3904~
1k | DR32
2.2k
/ | /

+ C15 r"

R36
~ c:::::J

## STATUS

PICEBS2 Microchip dev. board Power PICkit | DES !----+------------; REV | 28.05.2015 SNGB v1.2
HAUTE ECOLE VALAISANNE | 4/11 | {Path! PICEBS2_ V1 .2.sch

## ACTIVE

J. LD3
t~ BLUE

DR40
200

/

10k

R37 IVPP_GND) | c:::::J

10k

Q7
-t::: MMBT3904

/

5 | 7 | 8 | 10

A

B

C

D

E

F

UTIL_WP1); PROGAMMATION PICKIT; l.11CRO_l.4CLR; l,HCRO_PGD; SERIAL EEPROM; VCC; SCK; --------L: HOLD; vss 4; l+3.3V_PKI _l_C23 T 1u; UTIL_SDI); PIC24FJ256GB106; (ASSY_ID1); X1 ~ 12MHz T~; 330 I STATUS; MCLR; 0SCI/RC12 ASSY_ID0; RC13 (ASSY_l01); 48 RC14 40 0SCO/RC15; LED_ACTl'JE; (LED_REDI; ~;x LED_GREEN; VBUS/RF7; Condensateur 1 uF: AVDD et AVSS

PICEBS2 Microchip dev. board CPU PICkit | DES f---+-----------------1 REV | 28.05.2015 SNGB V1.2
HAUTE ECOLE VALAISANNE | 5/11 | !Poth! PICEBS2_ V1 .2.sch

1 | I | 2 | I | 3 | I | 4 | I | 5 | 6 | I | 7 | I | 8 | 9 | I | 10
A | Switch positions | A
Position | Remark

## 1 DEBUGER PICEBS2: PICEBS2 is enable and PICkit3 is enable

t-- | -
B | 2 | PICEBS2 is enable and PICkit3 is disable | B

## 3 Programmation target external

t-- | -
Switch positions | TARGET EXTERAL CONNECTOR C | C
IMCLR_EXT) | J3:1'
wus1 | [wus1 | '""' | ~
~
[JR52~)

. jt~,
I R53 | [JR55 | 10k ICSP =LVP | J3:6 t-- | DR54 | 470k | -
470k | 470k
. IRF7416 | IRF7416 | IRF7416 - | - | -
D | ~B | ;9 ll:J | 0/0 Ii:) | D "' | "' | "' . | ~ | ~~

~ ~ S1:D ~
~
13 | ~
S1:A | 1 | ~ | ~
2 | 0 3 | '\ 8 | IMCLR_EXT) | '\ 12 | IPGO_EXT) | '\ 16 | PGC_EXT) t-- | J, | -
'\ 4 | lvoD_TAR_cs)

'8US

. E | DR56 | U9 | 022 | E
10k | 3~ | _f' BSH207 VDO_ TAR_CS | 7
-1: | IC58
6 | TTT
~ | 4 | D __. | S | ~
5 Jvoo TAR ool 2 | 1,00n t-- | 9[}---1--x VBUS | - ~
' | 10
B | ~

GND
FSA2257MUX
F | Switch Current max: 200mA | PICEBS2 | DES | 28.05.2015 SNGB | F

### Microchip dev. board CONNECTOR

REV | V1.2
HAUTE ECOLE VALAISANNE | 6/11 | {Path! PICEBS2 V1 .2.sch
1 | I | 2 | I | 3 | I | 4 | I | 5 | 6 | I | 7 | I | 8 | 9 | I | 10

I | 2 | I

A

t--

B

R108 C

t--

D

t--

F

1 | I | 2 | I
3 | I

U10
LP3965EM-33
4 | I | 5 | I | 7

## Alimentation PICEBS

+3..3V_PIC_REG ~, VOLJTf-'3'-----.-------+------.-----r,------.-~l 3.3 V@ 1.500A max.

SENS~l 4

GND 'I

_LC30
ISBu ceramic
3 | I | 4

L04
~ GREEN

[ R58
390

I

P = 250rhW
C31 -~ C32 T,00p 6Bu ceramic

### PICEBS2 Microchip dev. board HAUTE ECOLE VALAISANNE

5 | 6 | I | 7
I | 8 | I | 10

A

B

## POINTS TEST

T

PT1 | PT2 | PT3 PT4 | C

D

E

DES | 28.05.2015 SNGB | F
POWER PICEBS2 | REV | V1.2
7/11 | {Path!
PICEBS2 V1 .2.sch
I | 8 | 9 | I | 10

A

## RESET BUTTON

B

C

D

12C_EXTERN_SDA | 12C_EXlERN_SCL

1 C34 I C35 ~ C36 1 C37 T 100n J 100n; 100n J 100n

/

C39 nl

2p
40
~ 22p
7 | 8 | 10

## PIC18F87K22

LED BUTION; INPUT INTERRUPT [; SPI r RS-232 (; CAN BUS; ~ LED4) ~ ~ '; ~ RJ0 L-""'-Jru=.\ RJ1 RJ2,---a,;-c"'""-''-l RJ3 RJ4'--""'---Jru=;\ RJ5,----,,-'-"=e/ RJ6 ,----,-.,-'-"'""-''J RJ7; LED BAR; DATA BUS

/

lx2

T32.768KHz

PICEBS2 Microchip dev. board CPU PICEBS2 | DES f---+-----------------1 REV | 28.05.2015 SNGB V1.2
HAUTE ECOLE VALAISANNE | 8/11 | {Path! PICEBS2_ V1 .2.sch

/

PIC18F87K22

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
GND; NC 40 XVJ; NHD-2.4-240320SF

D

## LCD driver

+3.3V_PIC

U12 6 vcc

2 INT

li,,oii)----~7--JDATA IN
(M'§C'f--,----------'iHA0/DATA_OUT

## 1---.-----"5'-_j~g~f

STMPE811

30 | RES 10 | CS
31 | | lt.10

## LCD

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
DB8 '--"'--'----'_r,;.;c..1
DB9
DB10
D811'--""-_r,;.;,.1
DB1 2 Lc<Q _ _r,;.;c;-:;\
DB13,.,.-'-'""~
PICEBS2 Microchip dev. board TOUCH DISPLAY | DES f---+------------------1 REV | 28.05.2015 SNGB V1.2
HAUTE ECOLE VALAISANNE | 9/11 | {Path! PICEBS2_ V1 .2.sch

BACKLIGHT SUPPLY VOLTAGE: 3.2 V BACKLIGHT SUPPLY CURRENT: 30 mA

A

B

C

D

E

F

BT1 LED0; BT1 LED1; LED1; LED2; BT2 LED0; BT2 LED1 -; LED2 -; 1+3.3V_PICI __L C60 T 100n; BT3_LED0 0; BT3_LED1 0; LED1 0; LED2 0; BUTTON INT0; BUTTON INT1; BUTTON BT3; ~ loi'D; Potentiometer; pot value is not significant between 10k to 4 70k; M63Mxx ,,-; Olimex UEXT; supply; Olimex standard communication; 26 pin 1/0 standard; ,J5,18 J- +3.3V_PIC; Keyboard (PS2); Ascom KB speed to be defined . normally: 11.36 kBds RJ 11; 4 clock is not used~; (EXTERN_LIART_RX_OUMEX; Hes-so/ /Extension; SUPPLY; PORTA; PORTB INTERRUPT; ] PORTC; COMMUNICATION l CCITTC COMMUNICATION; 1 eoe,e TOUCH COMMAND; l SCITTC CAN BUS; ] PORTG : PORTH; LED BAR; : PORTJ; DATA_ BUS; lveus_P1c_1NI

PICEBS2 Microchip dev. board 1/Q | DES f---+----------------; REV | 28.05.2015 SNGB V1.2
HAUTE ECOLE VALAISANNE | 10/11 | {Path! PICEBS2_ V1 .2.sch

LED BAR; CAN Bus; SPI MODE: 0,0 OR 1, 1; VDD; TXCAN; RXCAN; 3 CLKOIJT/SOF; RESIT; vss; MCP25151/ST I standby: BuA; +3.3V_PIC; tD16MHz C56; DC10SRWA; -±-D6 "'r" ZHCS 1000TA; RS-232 (DCE); connector acts as a PC connector; 1s vcc; The resistor 22 ohm and; the capacitor 4.7u; use to reduce supply noise; RS-232 Femelle; 1 EN INVALID 10 X; ___ 12,Fo~5~g~OFF"i--"16~___,,.==~ 14 GND; MAX3221CAE I standby: 10uA; CAN interface; R-RS could be changed for low CAN speeds; U18 l+3.31f_PI~ VCC; 2 GND SN65HVD231DR; to 0, else 1; Microchip dev. board; INTERFACE; HAUTE ECOLE VALAISANNE; REV; {Path! 11/11 PICEBS2_ V1 .2.sch

c,,_eow,aoow, CAN :et CAN POWERDOWN to use | ,
----------~I :st~a:n~d~by~:~1~u~A~----E~~~~~~~===== ~ | DES | 28.05.2015 SNGB | F PICEBS2

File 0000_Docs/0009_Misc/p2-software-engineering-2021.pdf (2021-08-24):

## Software Implementation for Embedded Systems

Pascal Sartoretti
Medard Rieder

HES-SO Valais, 2021

(c) HES-SO VS, sap, rim

Project II

### System

## Hardware



### System

## Proposed Architecture

XF

## XF Services

- XF is like an OS:
– events
– timers
– critical sections
- Services for events
– XF_popEvent
– XF_pushEvent
- Services for timers
– XF_scheduleTimer
– XF_unscheduleTimer
- Services for protection
– ENTERCRITICAL
– LEAVECRITICAL

## Events


### Event Queue

### Timer Queue

## Timers



### Timer Queue

## Cri

## tical Sec

## tions

### State Machine Pattern

## State Machine Pattern

Pattern for SM implementation using C
- Define enum with all states
- Define SM-variable using enum-type
- Set SM-Variable to initial state value in the
INIT-section of I-C-O
- Implement SM using a switch structure in order to control SM advancement
- Implement SM using a switch structure in order to implement actions
- Implement SM using the XF interface in order to control events and timers
- Each SM is a function with one parameter of type event

### Code

## SM Example

typedef enum SM1 {SM1ON, SM1OFF} SM1; SM1 sm1, oldsm1;

//init section
sm1 = SM1OFF;

//function
void f_sm1(Event e) {
//advancement control
oldsm1 = sm1;
switch (sm1) {
case: SM1OFF
if (e == evON)
sm1 = SM1ON;
break;
case: SM1ON
if (e == evOFF)
sm1 = SM1OFF;
break;
}

// action on entry control switch (sm1) {
case: SM1OFF
if (sm1old == SM1ON)
//do SM1OFF action on entry break;
case: SM1ON
if (sm1old == SM1OFF)
//do SM1ON action on entry break;


# Classes in C

### Classes in C

## Class - Pattern

Pattern for class implementation using C
- Attributes of class = struct
- Methods of class = function with first parameter of type struct (this pointer)
- Constructor = function that dynamically creates a struct, passes it to the init-function and finally returns a pointer to the struct
- Destructor = function that passes the struct to the cleanup function and the releases the struct.
- Objects = variables of type struct
- method call = call of function and pass reference to struct type variable

### Classes in C

## Class Example

struct A
{
int attrib;
}
void A_init(struct A* me)
{
me->attrib = 0;
}
struct A* A_create()
{
struct A* p;
malloc(p,sizeof(struct A)); if (p)
{
A_init(p);
}
return p;
}

void A_display(struct A* me) {
printf("%d", me->attrib);
}
void A_setAttrib(struct A* me,int p1) {
me->attrib = p1;
}
void A_destroy(struct A* me) {
free(me);
}
//use the class A
struct A* obj;
obj = A_create();
A_setAttrib(obj,3);
A_display(obj);
A_destroy(obj);


# Other Stuf

### Other Stuff

## Interrupts

- Convert interrupts in ISR to events
- Keep ISR as small as possible
- Do not forget that ISR stop execution of "main-land" code
- Be aware: ISR may use same memory as you are already using in main-land
- ISR can be considered as a very low level HAL
- NEVER allocate dynamic memory from within ISR code
- Use static, preconfigured events to convert interrupts to events

# Test Patterns

### Test Patterns

## Most Different Patterns

- Patterns
– Smoke testing
– Exploratory Testing
– Black box testing
– White box testing

### Test Patterns

## Smoke Test

- Quick test to see if software is operational
– Idea comes from hardware realm – turn power on and see if smoke pours out
– Generally simple and easy to administer
– Makes no attempt or claim of completeness
- Good for catching catastrophic errors
– Especially after a new build or major change
– Exercises any built-in internal diagnosis mechanisms
- But, not usually a thorough test
– More a check that many software components are “alive”

### Test Patterns

## Exploratory Testing

- A person exercises the system, looking for unexpected result
– Might or might not be using documented system behavior as a guide – Is especially looking for “strange” behaviors that are not specifically required nor prohibited by the requirements
- Advantages
– An experienced, thoughtful tester can find many defects this way – Often, the defects found are ones that would have been missed by more rigid testing methods
- Disadvantages
– Usually no documented measurement of coverage
– Can leave big holes in coverage due to tester bias/blind spots
– An inexperienced, non-thoughtful tester probably won’t find the important bugs

### Test Patterns

## Black Box Testing

- Tests designed with knowledge of behavior
– But without knowledge of implementation
– Often called “functional” testing
- Idea is to test what software does, but not how function is implemented
- Advantages:
– Tests the final behavior of the software
– Can be written independent of software design
•Less likely to overlook same problems as design
– Can be used to test different implementations with minimal changes
- Disadvantages:
– Doesn’t necessarily know the boundary cases
•For example, won’t know to exercise every lookup table entry
– Can be difficult to cover all portions of software implementation

### Test Patterns

## White Box Testing

- Tests designed with knowledge of software design
– Often called “structural” testing
- Idea is to exercise software, knowing how it is designed
- Advantages:
– Usually helps getting good coverage (tests are specifically designed for coverage)
– Good for ensuring boundary cases and special cases get tested
- Disadvantages:
– 100% coverage tests might not be good at assessing functionality for “surprise” behaviors and other testing goals
– Tests based on design might miss bigger picture system problems – Tests need to be changed if implementation/algorithm changes

# Testing

### Test Scenarios

## How To Test

- Test situations with applications of patterns – Unit test
– Subsystem test
– System integration test
– Acceptance test
– Beta test

### Test Scenarios

## People Involved To Test Scenarios

- Different people play roles of tester:
– Programmer (YOU) often does own testing for
- unit tests
– Independent testers (OTHER GROUP) are often involved in
- subsystem test
- system test
- acceptance tests
– Customers (MR. SARTORETTI) are often involved in
- acceptance tests
- beta tests

### Test Scenarios

## Testing

- Unit test
– smoke and white box pattern, programmer on development system
- Subsystem test
– white box pattern, programmer on different development systems
- System integration test
– black box pattern, programmer and test persons on development and test systems
- Acceptance test
– smoke and black box pattern, test person on virgin system
- Beta test
– exploratory, any person on any system

### HOW TO

## Test template

Test ID | Give each Test an unique name or ID
Description | Precisely describe what this test is supposed to test.
Pattern | Select a test Pattern (smoke, exploratory, black box, white box)
Test prescription | Precisely describe how this test has to be executed. Describe in which state the DUT has to be at the begin of the test(device under test) has to be at the begin of the test. Describe tools or other materials needed for the test.
Personel | Describe which persons are involved in the test and also describe the exact role of each person during this test.
Results | Describe the results of the test in a completely factual manner.
Conclusions | Make a concluding statement concerning the test and its results
Measures | Describe eventual measures to be taken. Also describe who has to take which measure. Do not forget to give a due date for each measure.

### HOW TO

## Test Example

Test ID | HW 03
Description | This test has to verify if the PCB has no short cuts
Pattern | white box
Test prescription | The PCB is connected to a laboratory power supply. The power supply has the voltage regulated to 3 Volts and the current s limited to 20 mA. The power leads are connected to the corresponding battery clips. Power is applied to the board. If a short circuit is shown, the power is switched off immediately. If no short circuit is seen, the current is documented. Power is switched off. This ends the test.
Personel | The test is run by Pascal
Results | No short circuit has been observed. The current consumption was 7 mA.
Conclusions | The consumption of 7 mA is maybe due to the micro controller that is not yet configured. The test shows that there is principally no problem with the PCB.
Measures | Since this test is good, testing continues to test HW 04

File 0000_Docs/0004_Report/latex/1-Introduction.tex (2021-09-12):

\begin{summary}
\section{Contexte}
Ce projet a été réalisé dans le cadre du cours
\emph{Summer School 2 - Infotronic} de la Haute école d'ingénieur du Valais.
Ce cours de 3 semaines se passe à la fin de l'été, avant la reprise de
septembre. Il a pour but de mettre en pratique les compétences acquises
durant la 2e année du bachelor.\\
L'objectif du projet est de développer une console de jeu portable,
avec écran tactile, permettant de jouer au jeu \emph{Pong}.\\
Normalement, des équipes de 2 personnes sont formées, mais
dû au fait que nous sommes un nombre impaire, je me suis retrouvé à développer
le PongBoy seul.
\end{summary}

\section{Spécifications}
\begin{itemize}
  \item La console doit être alimentée par 2 piles AAA en série, et ainsi
  fonctionner en $3[V]$.
  \item Une protection contre l'inversion de polarité des piles doit être
  présente.
  \item La console doit pouvoir être mise en veille ultra-basse-consommation,
  pour éviter de changer les piles AAA trop régulièrement.
  \item L'écran tactile résistif NHD-2.4-240320SF-CTXL-FTN1 doit être utilisé,
  et une interface tactile doit être implémentée.
  \item L'utilisation d'une puce driver pour l'écran tactile est prohibée,
  une librairie driver est fournie.
  \item Le micro-controlleur PIC18LF25K22 doit être utilisé, au format SOIC,
  pour ses capacités d'ultra-basse-consommation.
  \item L'alimentation de l'écran LCD ainsi que de son rétro-éclairage doit
  pouvoir être coupée pour respecter la contrainte d'ultra-basse-consommation.
\end{itemize}

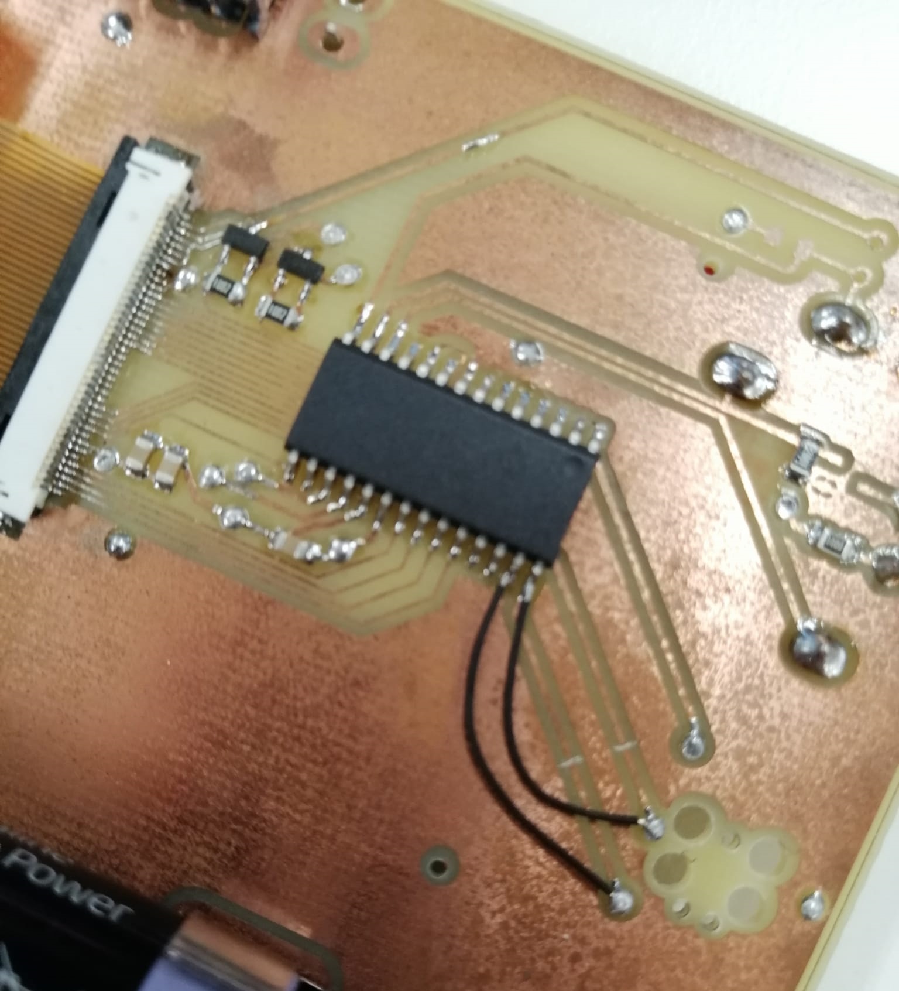
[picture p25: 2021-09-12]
0000_Docs/0004_Report/latex/Images/c_moche.jpeg

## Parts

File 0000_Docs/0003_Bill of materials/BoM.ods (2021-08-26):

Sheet: Bill_of_Material
Type | Part | Value | Package | Distributor | Unit | Qty | Description | art./isbn | Unit price | Total price | Comment
LDR | R8 | 10kOhm | - | Mouser | 1 piece | 2 | Light-Dependant Resistor Sparkfun | 474-SEN-09088 | CHF 1.40 | CHF 2.80
Speaker | SP1 | - | Solder Pin | Mouser | 1 piece | 1 | Haut-parleurs et transducteurs 3VP-P 70MA 20 OHM 86DBA | 665-AT0927TT3R | CHF 1.80 | CHF 1.80
N-MOS | T1, T2, T3, T4 | - | SOT23-3 | Mouser | 1 piece | 8 | Transistor MOSFET Canal N, Rds On 25mOhms | 771-PMV13XNEAR | CHF 0.42 | CHF 3.37
 |  |  |  |  |  |  | Prout Samy Prout Prout

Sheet: List
Distributor
Distrelec
Farnell
Mouser

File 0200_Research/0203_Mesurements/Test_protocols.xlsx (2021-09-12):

Test ID | Hardware - 01 | Test ID | Firmware - 01
Description | Inspection des défauts de fabrication | Description | Programmabilité du micro contrôleur
Pattern | White Box | Pattern | White Box
Test Description | Le PCB, juste après la fabrication et l'usinage, est inspecté à la loupe dans le but de rechercher d'éventuelle court circuit entre les pistes ou alors des pistes coupées qui aurait été rongée par l'acide | Test Description | On lance MPLAB puis on crée un nouveau projet avec le bon compilateur (XC8) et le bon PIC (18LF25k22). Le PCB vient se connecter avec le connecteur de programmation sur l'ordinateur. Une première compilation et programmation est lancée. Si le programme s'arrête avec une erreur, on débranche le Pickit3 et on cherche la faute. Sinon, le test prend fin.
Personnel | Samy Francelet | Personnel | Samy Francelet
Results | 2 pistes coupées : PGC et PGD | Results | MPLAB ne reconnait pas le micro contrôleur
Conclusions | Le cuivre de la face supérieur a été plus mangé par l'acide, les pistes fines du port de programmation en ont souffert | Conclusions | Les pins PGC et PGD sont inversées
Measures | Un morceau de fil conducteur a été soudé par-dessus la piste | Measures | Les deux pistes sont coupées et deux fils sont utilisés à la place
Test ID | Hardware - 02 | Test ID | Firmware - 02
Description | Ce test permet de vérifier si le PCB n'a pas de court-circuit | Description | Changement de couleur de fond d'écran
Pattern | Smoke test | Pattern | White Box
Test Description | Le PCB assemblé complet va être inspecté à la loupe, puis alimenté en 3V, avec une limitation de courant <150mA pour éviter de faire de trop gros dégats en cas de court-circuit. | Test Description | Vérifie que la commande tactile fonctionne, et que la communicaiton avec l'écran fonctionne
Personnel | Samy Francelet | Personnel | Samy Francelet
Results | Pas de court-circuit observé. Le courant est <10mA. | Results | Fonctionnel
Conclusions | Ce courant correspond à la consommation du PIC n'étant pas encore programmé. | Conclusions | Le test est reussi
Measures | Le test est réussi. | Measures
Test ID | Hardware - 03 | Test ID | Firmware - 03
Description | Ce test permet de vérifier la protection contre l'inversion de polarité | Description | Balle qui rebondit contre les parois de l'écran
Pattern | Smoke test | Pattern | White Box
Test Description | On inverse la polarité de l'alimentation afin de voir si notre protection fonctionne correctement | Test Description | Vérifie que le contrôleur de jeu fonctionne et que les collisions sont correctes
Personnel | Samy Francelet | Personnel | Samy Francelet
Results | Pas d'échauffement de composant. Pas de courant | Results | Aucun bug de rebond
Conclusions | La protection d'alimentation fonctionne correctement | Conclusions | Le test est réussi
Measures | Le test est réussi. | Measures
 |  | Test ID | Firmware - 04
 |  | Description | Test du sleep
 |  | Pattern | White Box
 |  | turn | On vérifie que l'appereil s'éteint belle et bien après 20 sec
 |  | Personnel | Samy Francelet
 |  | Results | L'appareil s'éteint correctement
 |  | Conclusions | Le test est réussi
 |  | Measures
 |  | Test ID | Firmware - 05
 |  | Description | Stress test du jeu Pong
 |  | Pattern | Black box
 |  | Test Description | Vérifier que le programme répond correctement, même si plusieurs utilisateurs viennent essayer le jeu, faire des commandes absurdes, appuyer avec 12 doigts, etc..
 |  | Personnel | Samy Francelet
 |  | Results | Aucun bug détecté
 |  | Conclusions | Le test est réussi
 |  | Measures

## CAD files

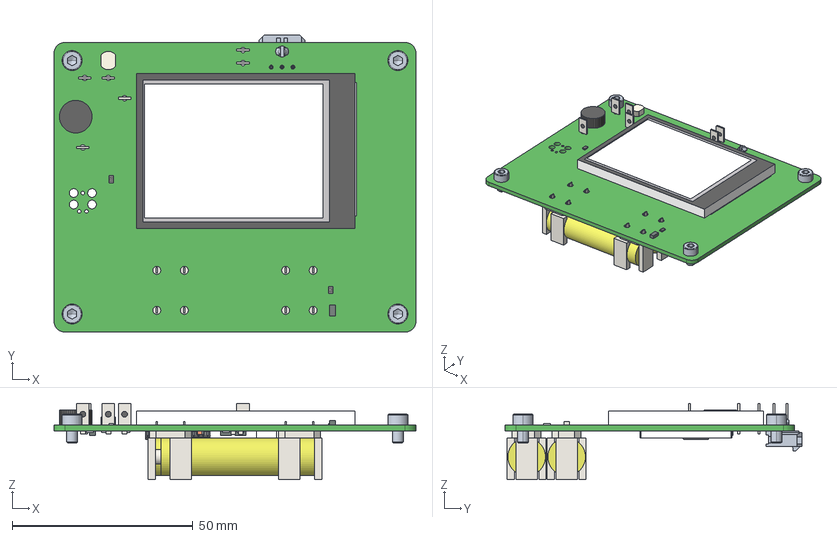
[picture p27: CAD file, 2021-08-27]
0400_Mechanical/PongBoy.step
100.0 x 82.1 x 21.1 mm
Extruded x 56
User_Library-SO-28W__X2_041A043E0440043F04430441_X0_
User_Library-SO-28W__X2_041C04350442043A0430_X0_
User_Library-SO-28W__X2_041D043E0436043A0430_X0_ x 14
User_Library-RESC2012X05N x 7
din_7500_-_e_m3_x_5_-_st x 4

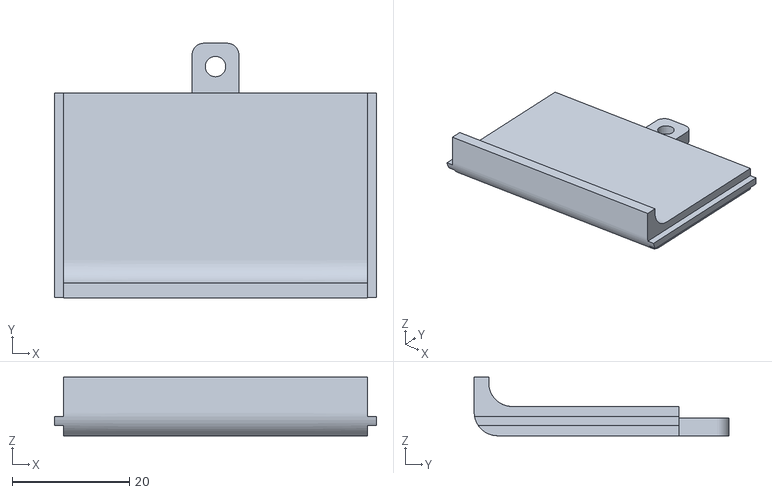
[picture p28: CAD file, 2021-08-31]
0700_Fab/0702_Mechanical/Case V2.1/P3_BatteriesTray.stl
55.0 x 43.5 x 10.0

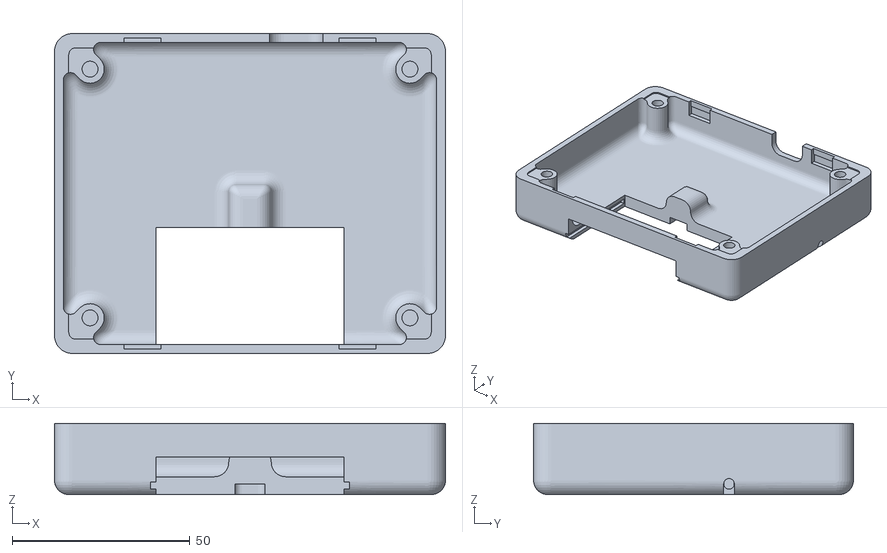
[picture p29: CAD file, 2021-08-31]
0700_Fab/0702_Mechanical/Case V2.1/P1_BottomCase.stl
110.0 x 90.0 x 20.0

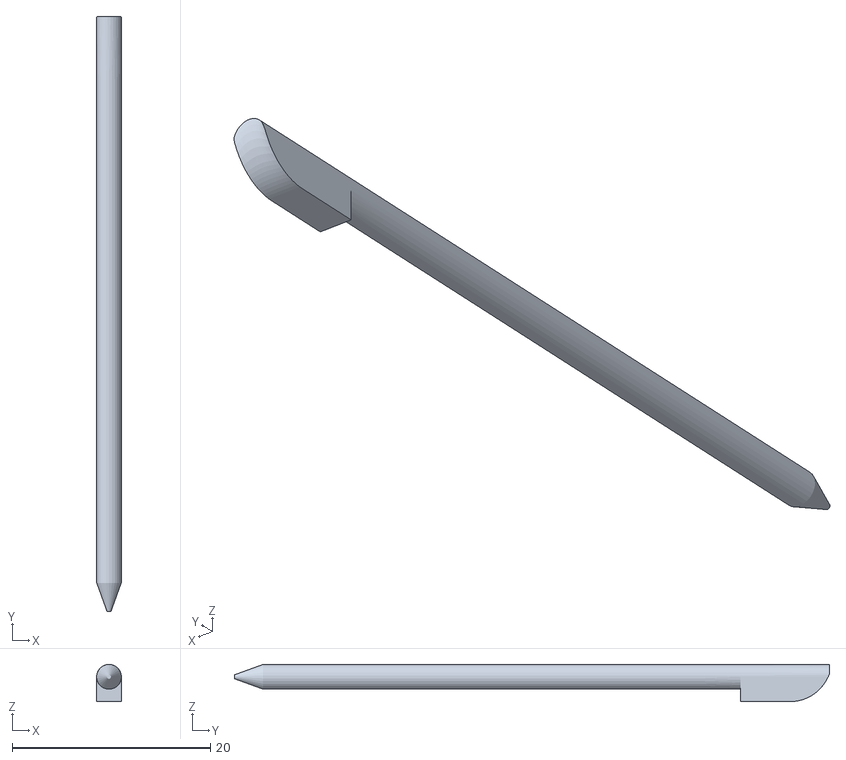
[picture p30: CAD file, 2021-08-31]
0700_Fab/0702_Mechanical/Case V2.1/P4_Stylet.stl
2.50 x 60.0 x 3.75

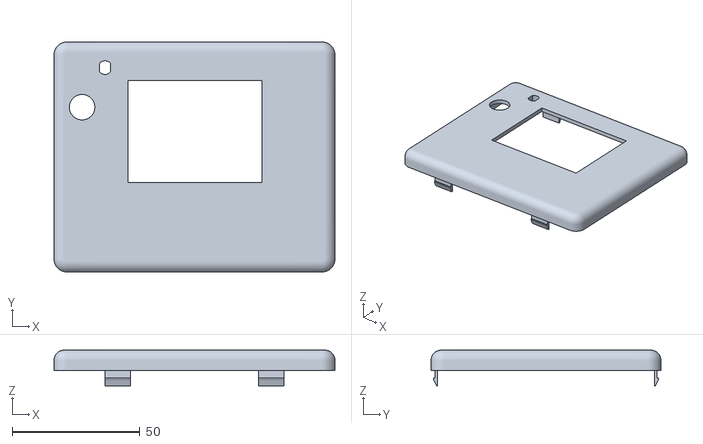
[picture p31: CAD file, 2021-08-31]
0700_Fab/0702_Mechanical/Case V2.1/P2_TopCase.stl
110.0 x 90.0 x 14.0

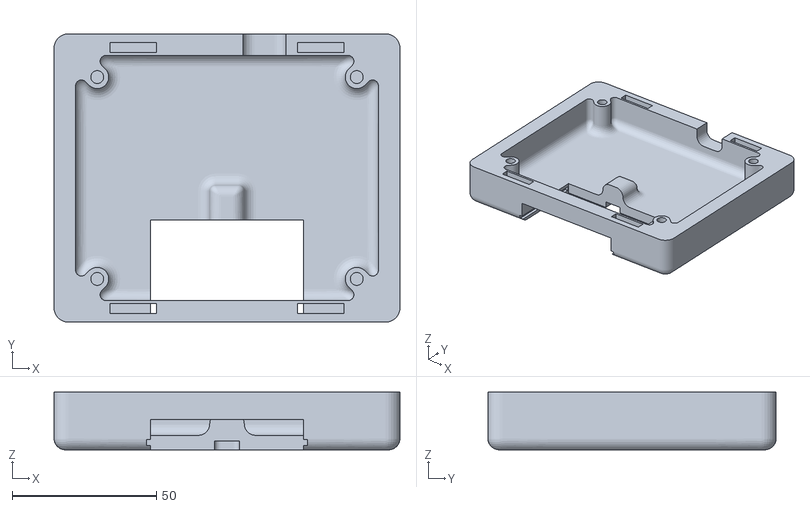
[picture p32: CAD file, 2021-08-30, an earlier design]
0700_Fab/0702_Mechanical/Case V1.1/P1_BottomCase.stl
120.0 x 100.0 x 20.0

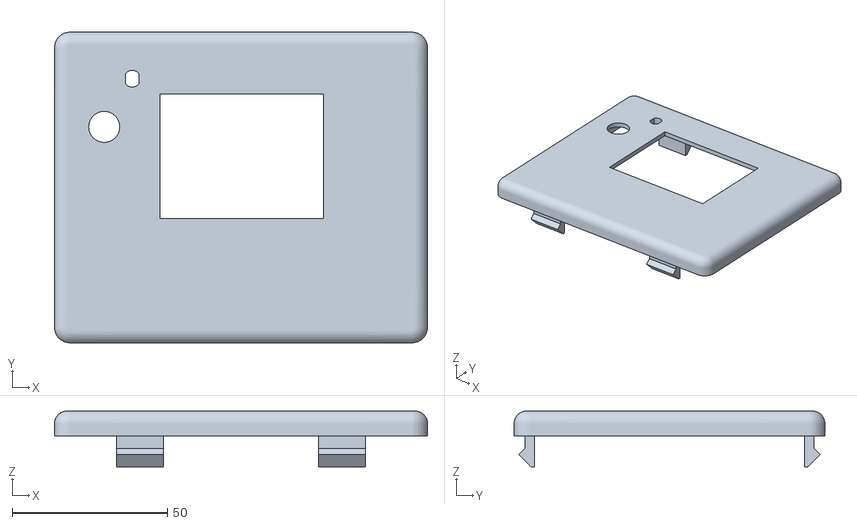
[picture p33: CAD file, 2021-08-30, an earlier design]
0700_Fab/0702_Mechanical/Case V1.1/P2_TopCase.stl
120.0 x 100.0 x 18.0

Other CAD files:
0700_Fab/0702_Mechanical/Case V1.1/P3_BatteriesTray.stl
0400_Mechanical/A2_PongBoy.iam
0400_Mechanical/A2_PongBoy.idw
0400_Mechanical/A2_PongBoy.ipn
0400_Mechanical/A3_BatteriesTray.ipt
0400_Mechanical/OldVersions/A2_PongBoy.0007.ipn
0400_Mechanical/OldVersions/A2_PongBoy.0009.idw
0400_Mechanical/OldVersions/A2_PongBoy.0014.iam
0400_Mechanical/OldVersions/A2_TopCase.0014.ipt
0400_Mechanical/OldVersions/A3_BatteriesTray.0004.ipt
0400_Mechanical/OldVersions/P1_BottomCase.0068.ipt
0400_Mechanical/OldVersions/P2_TopCase.0039.ipt
0400_Mechanical/OldVersions/P3_BatteriesTray.0008.ipt
0400_Mechanical/OldVersions/P4_Stylet.0002.ipt
0400_Mechanical/P1_BottomCase.ipt
0400_Mechanical/P2_TopCase.ipt
0400_Mechanical/P3_BatteriesTray.ipt
0400_Mechanical/P4_Stylet.ipt

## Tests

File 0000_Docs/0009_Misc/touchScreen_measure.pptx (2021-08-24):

## How to use a resistive touchscreen TOUCHSCREEN

SummerSchool - 2019
Pascal Sartoretti
(pascal.sartoretti@hevs.ch)

## What’s a resistive touchscreen?

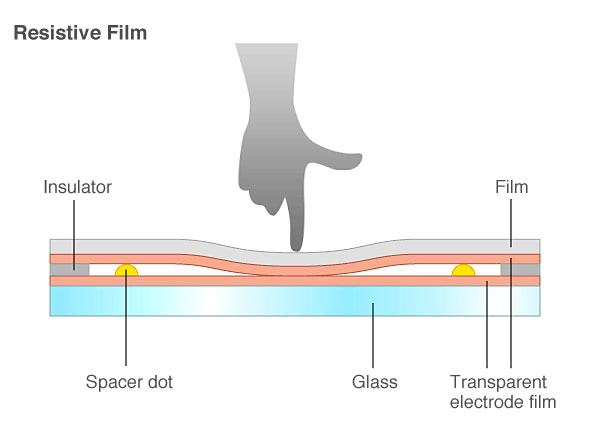
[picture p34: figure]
RÃ©sultat de recherche d'images pour "resistive touchscreen"

## How it works

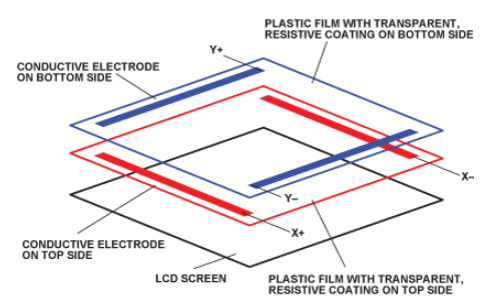
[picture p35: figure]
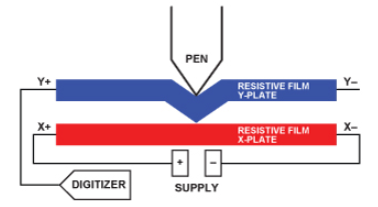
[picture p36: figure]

## How to measure (with STMPE811)

Advantages:
- I2C interface (easy)

Disadvantages:
- price (2.30 CHF)
- very hard to weld (for students ;-)
- only manufacturer capabilities
- power consumption

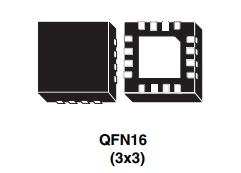
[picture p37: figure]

## How to measure without any dedicated IC

Advantages:
- Cheap
- Upgradable
- Zero power (interrupt mode)

Disadvantages:
- A little bit more code

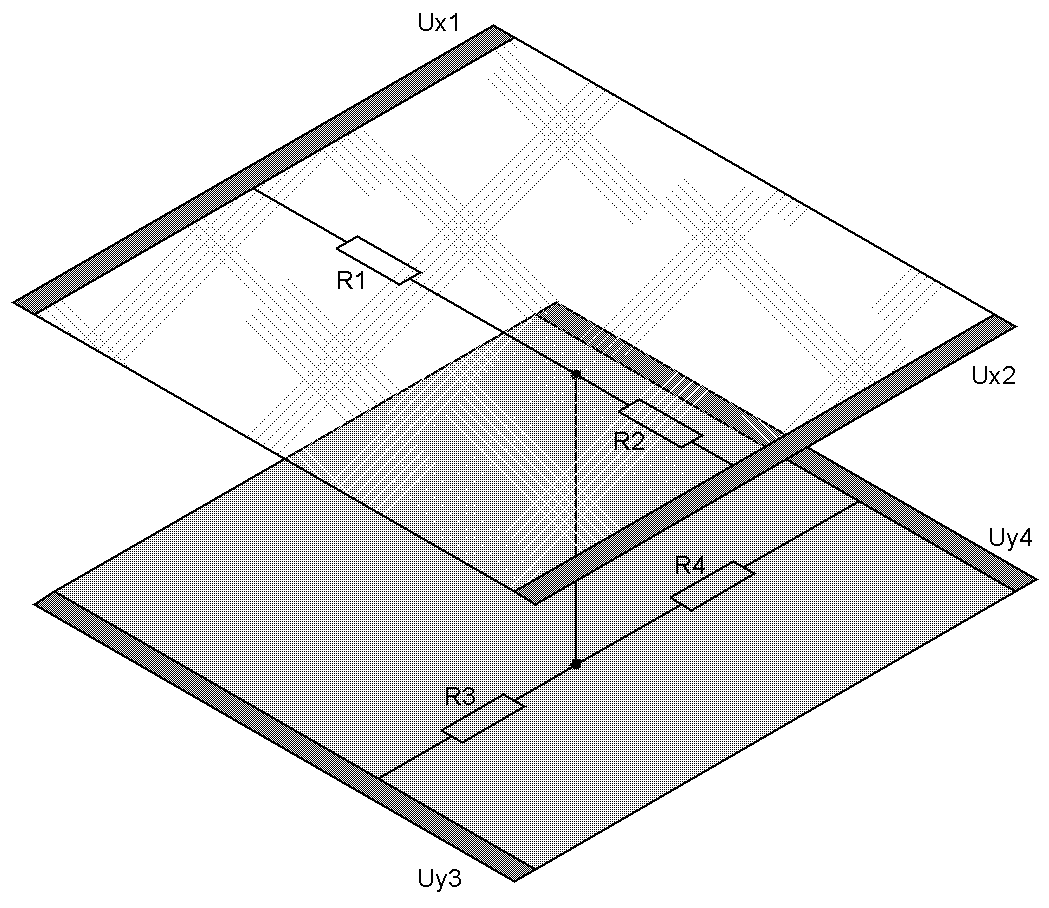
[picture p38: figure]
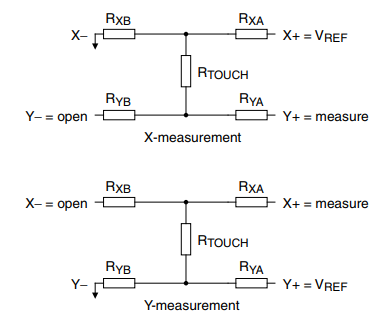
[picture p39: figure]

## How to detect pressure with interrupts

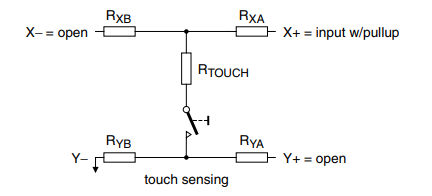
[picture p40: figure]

## Coding idea

- Wait for touch interrupt
- Measure X, Y and Z with interrupt mode
- When no more pressure, wait touch interrupt again
- Don’t forget to use uC pin with interrupt and analog input capability
- Improvements: two fingers gesture recognition
(see: “AD7879 Controller Enables Gesture Recognition on Resistive Touch Screens” on the web)

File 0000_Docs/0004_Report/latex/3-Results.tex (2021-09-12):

\section{Résultats}
\begin{figure}[H]
  \centering
  
  \caption{Boîtier complet du PongBoy}
  \label{mech_pongboy}
\end{figure}
Le cahier des charges est respecté. La jouabilité est correcte.
Par manque de temps, et manque de ressources humaines,
les fonctionnalités comme le haut-parleur, et le mode multi-joueur n'ont pas
pu être implémentés.
\newpage

\section{Test}
De nombreux tests ont été réalisés pour vérifier la qualité du produit.
Ces tests ont permis de détecter de nombreux problèmes, qui ont bien
entendu été corrigés.
\begin{figure}[H]
  \centering
  
  \caption{Signaux de programmation PGC et PGD inversés}
  \label{c_moche}
\end{figure}
Par exemple, les signaux PGC et PGD du port de programmation ont été inversé
dans la schématique, résultant en une impossibilité de programmer le processeur.
Cela a été corrigé comme montré dans la figure 3.2

L'ensemble des tests réalisés durant ce projet sont disponibles en Annexe A.

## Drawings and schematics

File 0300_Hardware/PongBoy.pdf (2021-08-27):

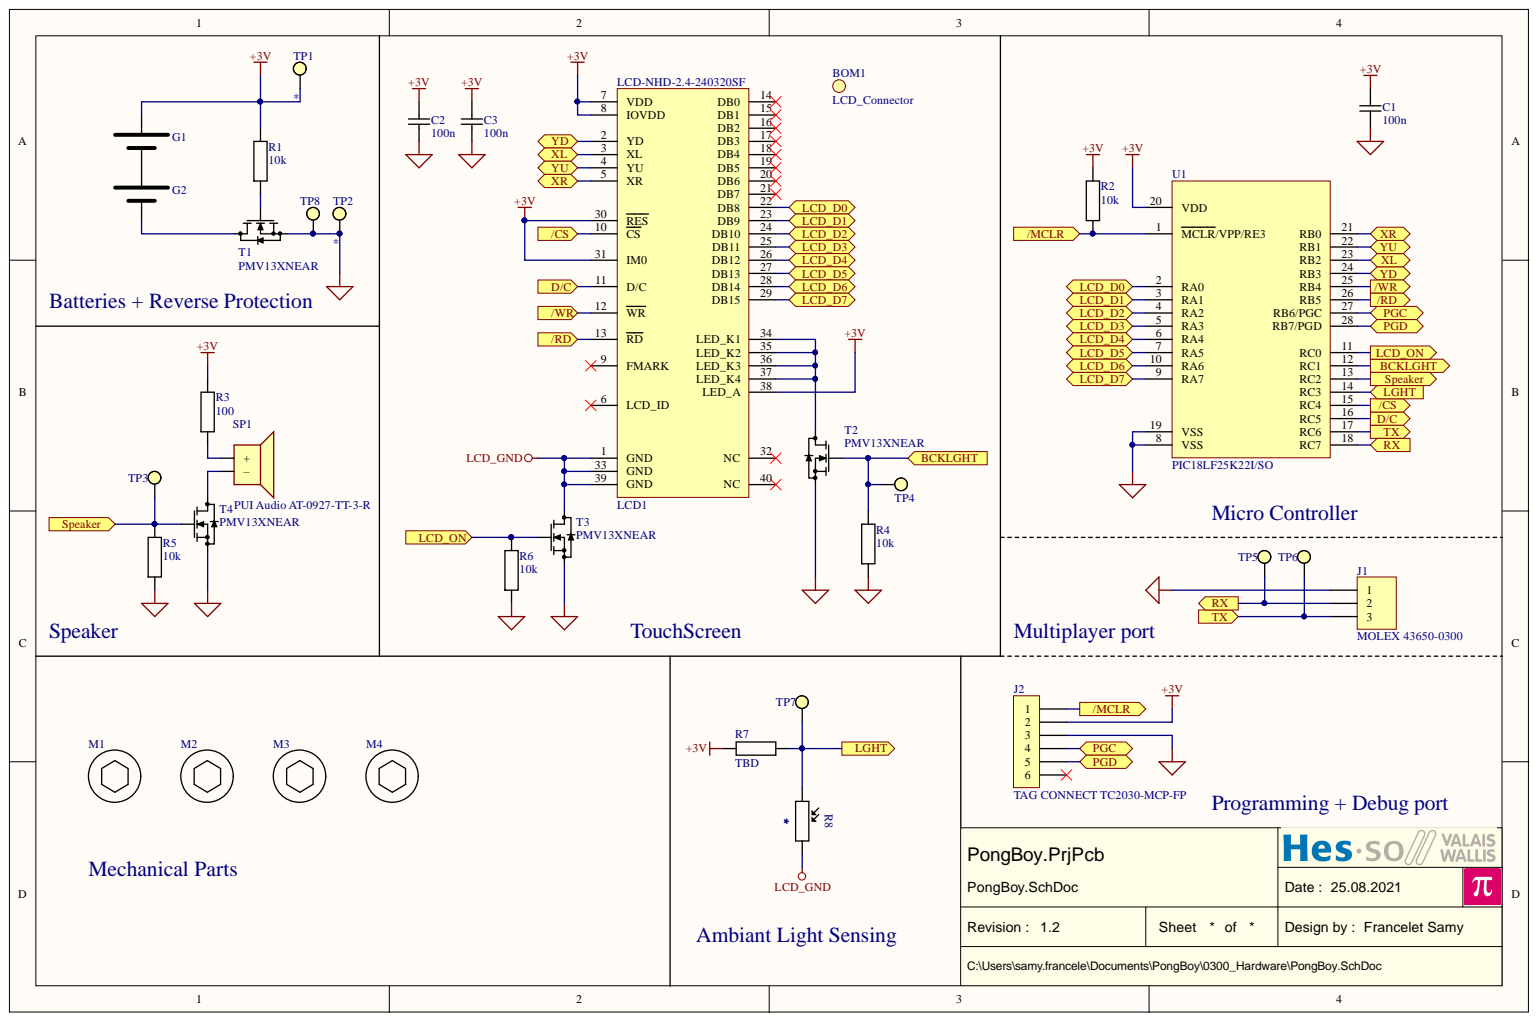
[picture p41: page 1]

PUI Audio AT-0927-TT-3-R

PongBoy.PrjPcb PongBoy.SchDoc

Date : 25.08.2021

Revision : 1.2 | Sheet * of * | Design by : Francelet Samy

C:\Users\samy.francele\Documents\PongBoy\0300_Hardware\PongBoy.SchDoc

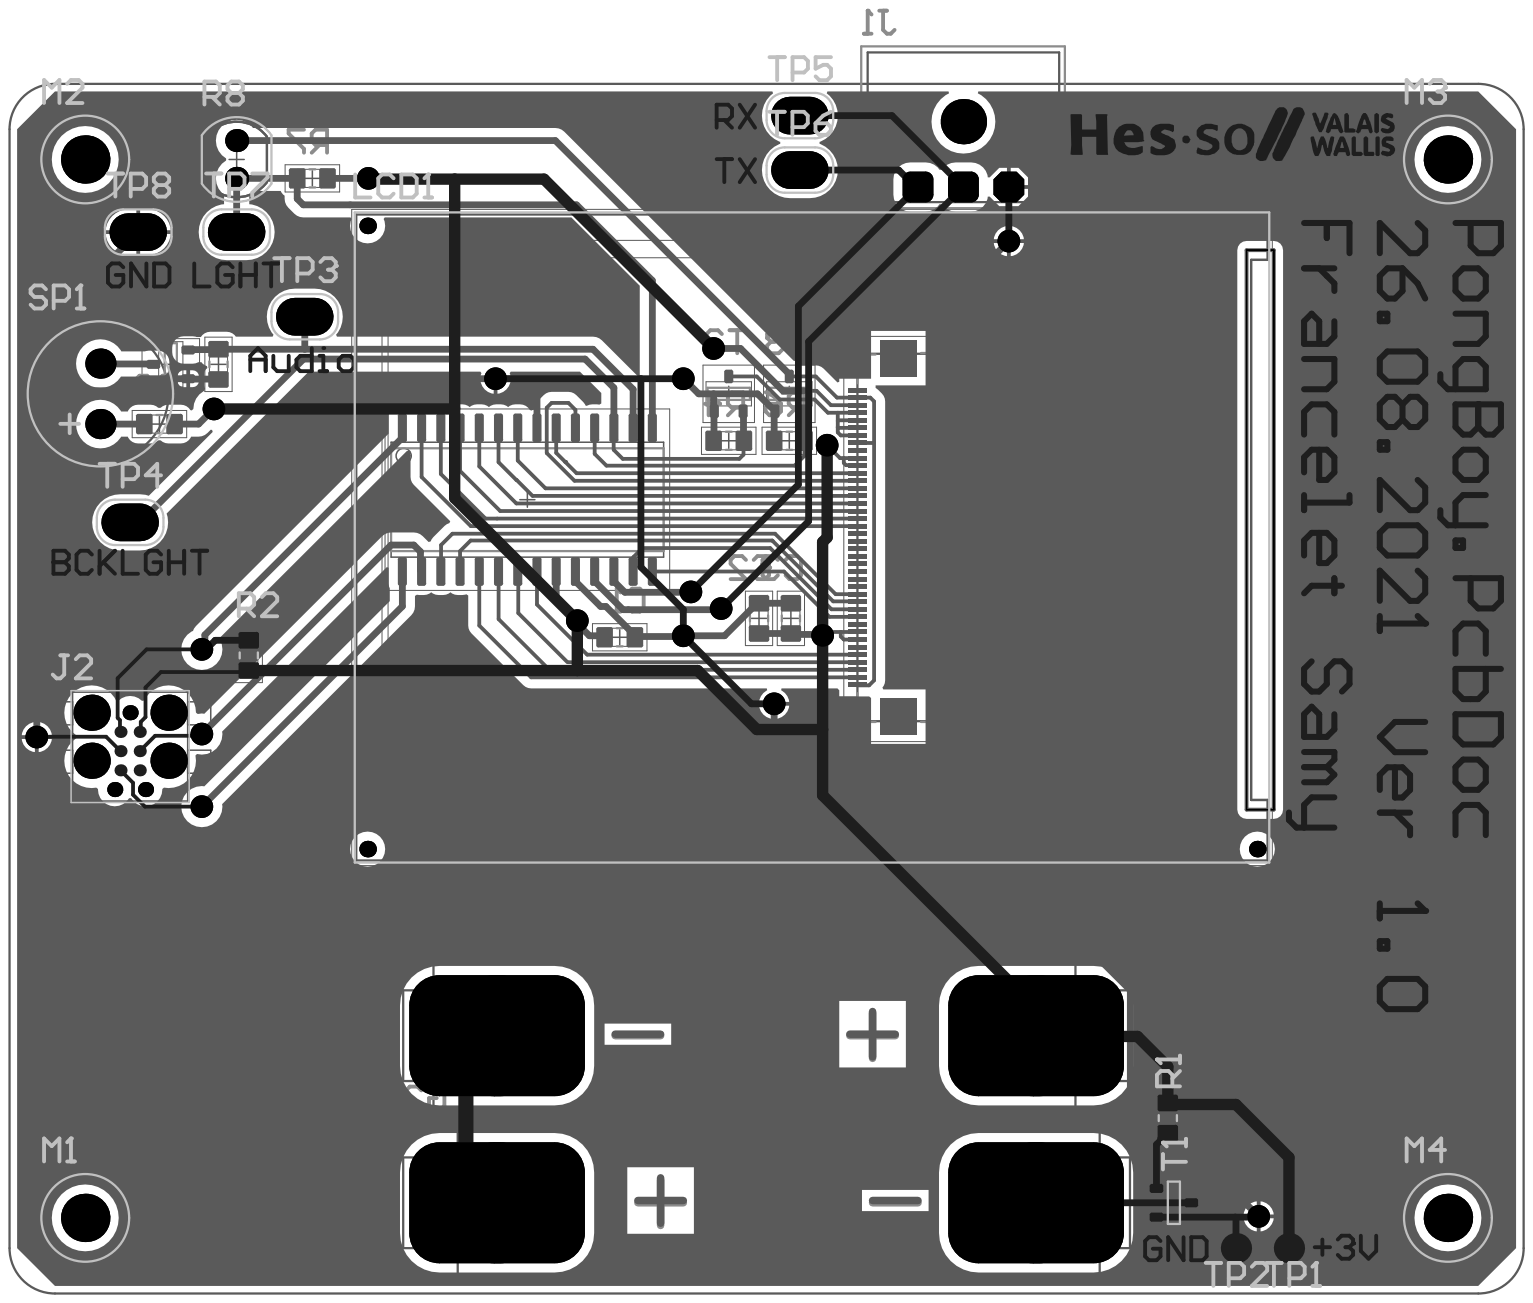
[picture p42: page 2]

Item # | Designator | Description | Name | Quantity | Manufacturer 1 | Manufacturer Part Number 1
1 | BOM1 | Component without pattern | LCD_Connector | 1 | Molex | 52271-1279
2 | C1, C2, C3 | Capacitor | 100n | 3 | Kyocera AVX | 08055C104K4Z2A
3 | G1, G2 | Battery Generic | AAA Battery Holder | 2 | Keystone Electronics | 1021
4 | J1 | Micro-Fit 3.0 Right-Angle Header, 3.00mm Pitch, Single Row, 3 Circuits MOLEX 43650-0300 | | 1 | Molex | 436500300
5 | J2 | TAG CONNECT TC2030-MCP-FP | TAG CONNECT TC2030-MCP-FP | 1
6 | LCD1 | NEWHEAVEN LCD | LCD-NHD-2.4-240320SF | 1 | Newhaven Display | NHD-2.4-240320SF-CTXI#-1
7 | M1, M2, M3, M4 | Screw Hex Socket Unconnected BN610M3x20 | | 4 | TR Fastenings | M320SOA2CSS50-
8 | R1, R2, R4, R5, R6 | Resistor | 10k | 5 | Vishay | CRCW080510K0FKEA
9 | R3 | Resistor | 100 | 1 | Vishay Dale | CRCW0805100RFKEA
10 | R7 | Resistor | TBD | 1 | Vishay | CRCW08050000Z0EA
11 | R8 | Light Dependent Resistor | | 1 | SparkFun | SEN-09088
12 | SP1 | Speaker PUI Audio AT-0927-TT-3-R | PUI Audio AT-0927-TT-3-R | 1 | Projects Unlimited | AT-0927-TT-3-R
13 | T1, T2, T3, T4 | Generic MOS-N | PMV13XNEAR | 4 | Nexperia | PMV13XNEAR
14 TP3, TP4, TP5, TP6, TP7, TP8 Test Point | | | | 6 | Keystone Electronics | 1035
15 | U1 | Flash Microcontrollers with 10-Bit A/D and nanoWatt Technology PIC18LF25K22I/SO | | 1 | Microchip | PIC18F25K22-E/SO

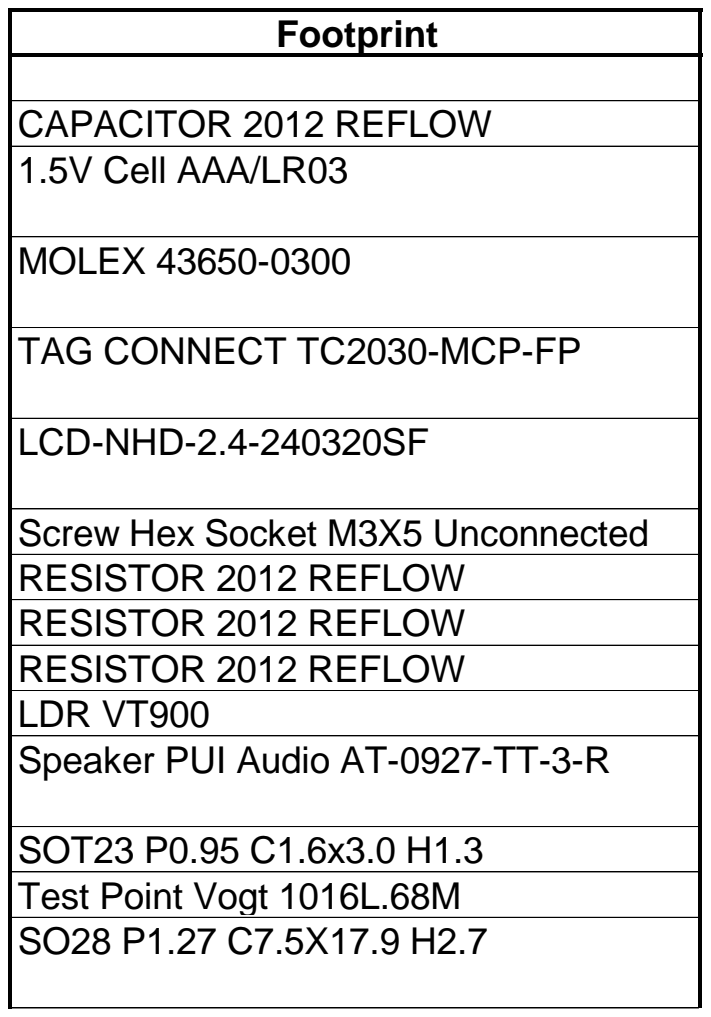
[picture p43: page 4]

TAG CONNECT TC2030-MCP-FP

Screw Hex Socket M3X5 Unconnected
RESISTOR 2012 REFLOW
LDR VT900
Speaker PUI Audio AT-0927-TT-3-R

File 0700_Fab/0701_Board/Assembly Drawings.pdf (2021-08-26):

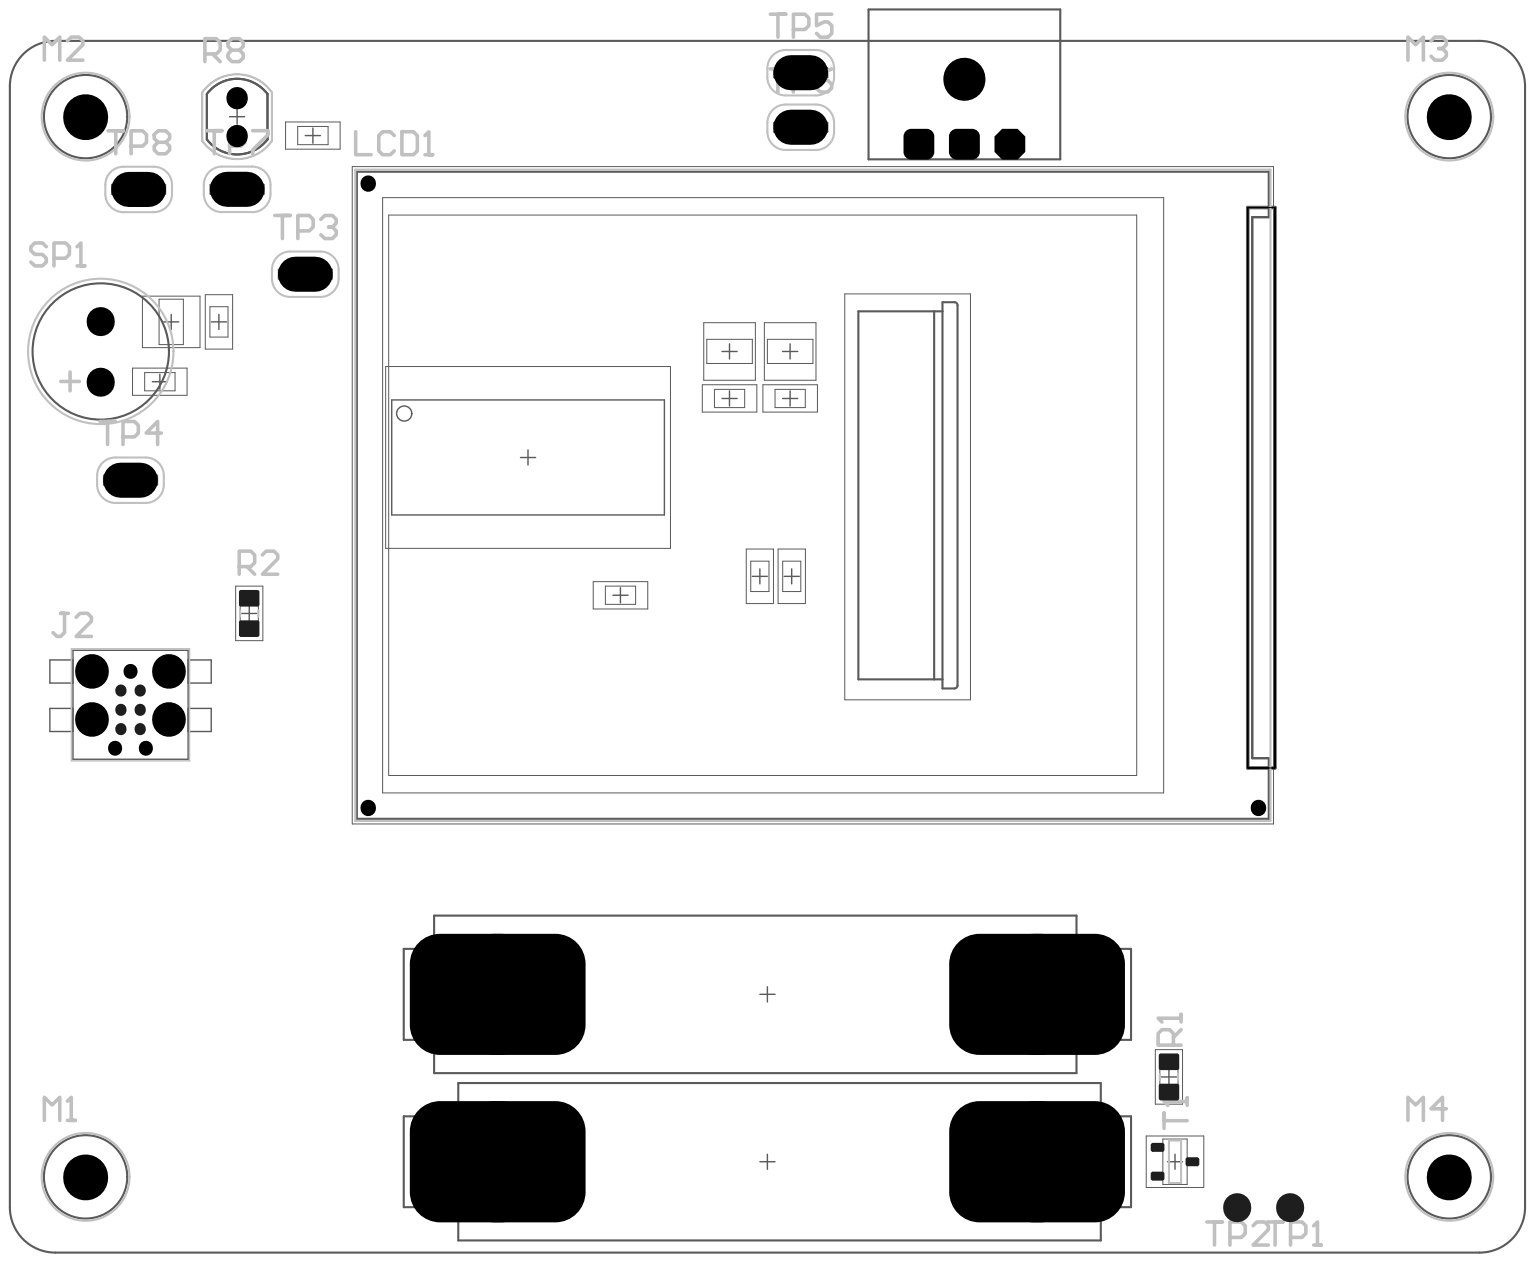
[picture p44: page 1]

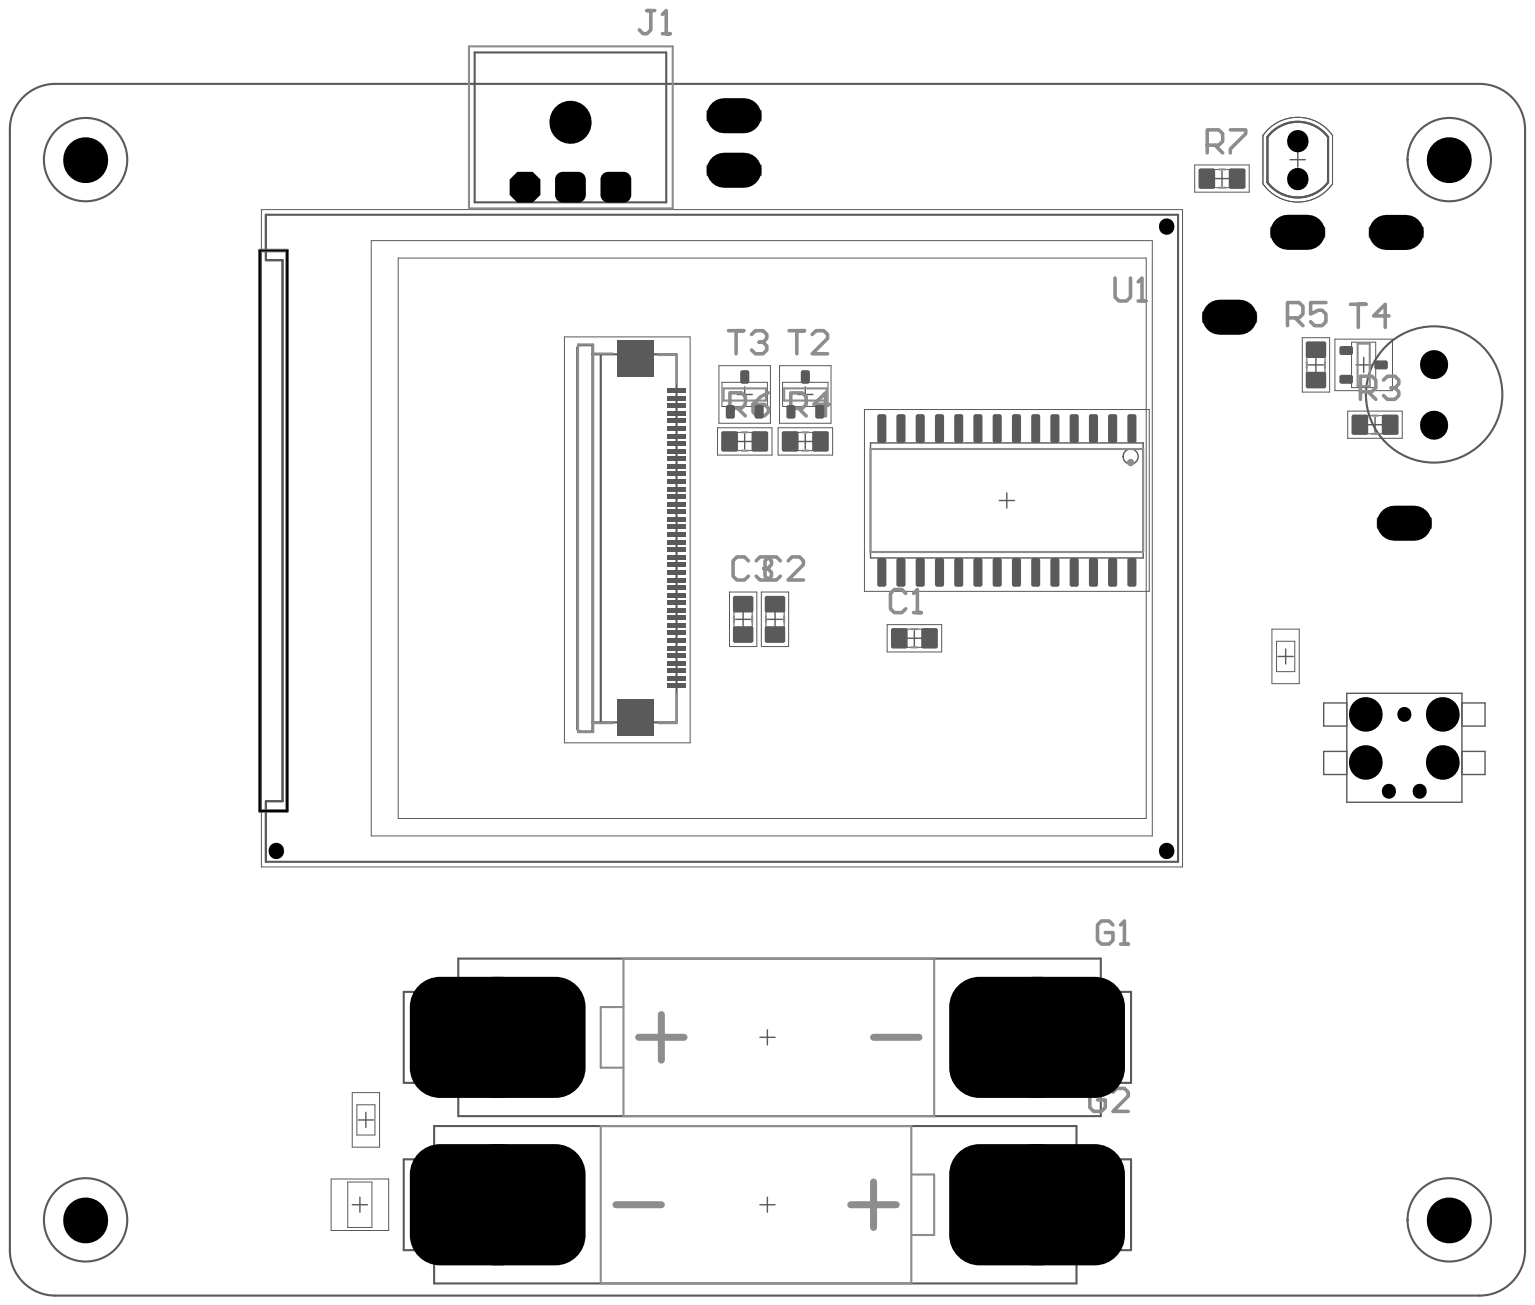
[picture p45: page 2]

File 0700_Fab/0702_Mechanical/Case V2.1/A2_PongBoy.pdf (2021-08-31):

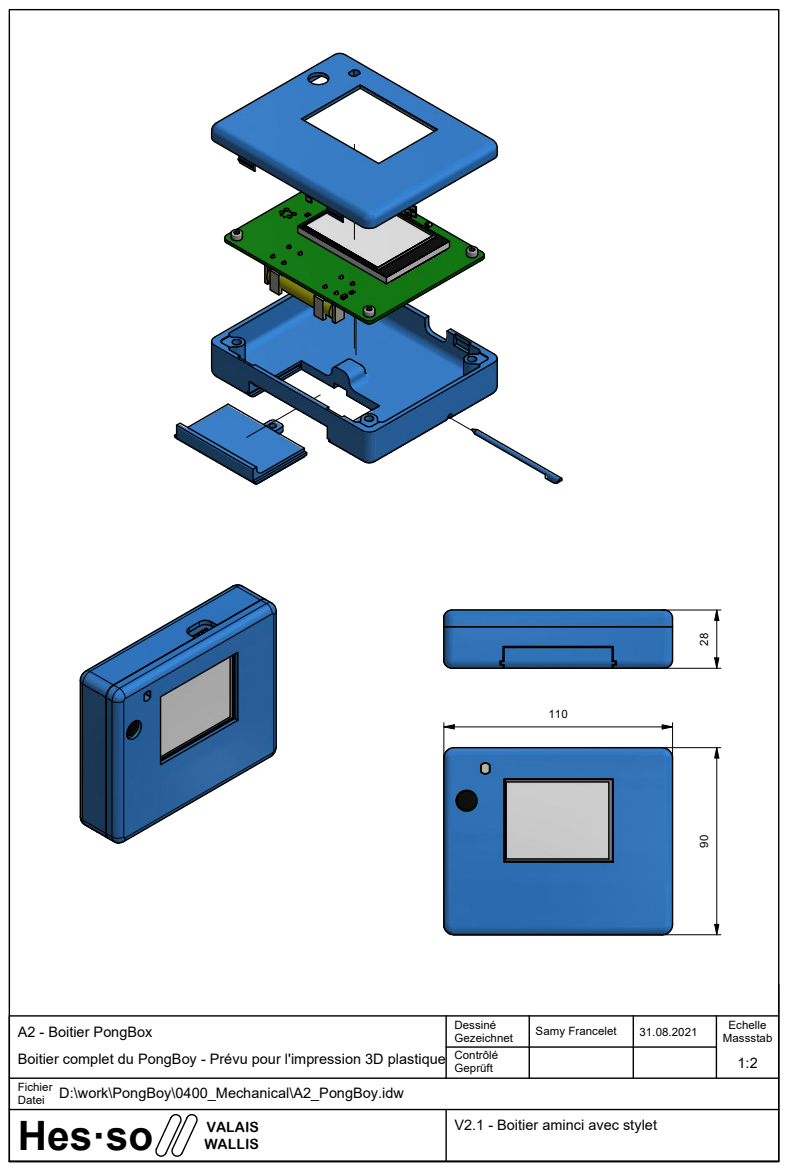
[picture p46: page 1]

A2 - Boitier PongBox Boitier complet du PongBoy - Prpvu pour l'impression 3D plastique | Dessinp Gezeichnet | Samy Francelet | 31.08.2021 | Echelle Massstab 1:2

Contr{lp Geprüft

D:\work\PongBoy\0400_Mechanical\A2_PongBoy.idw

V2.1 - Boitier aminci avec stylet

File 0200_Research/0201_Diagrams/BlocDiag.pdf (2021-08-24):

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

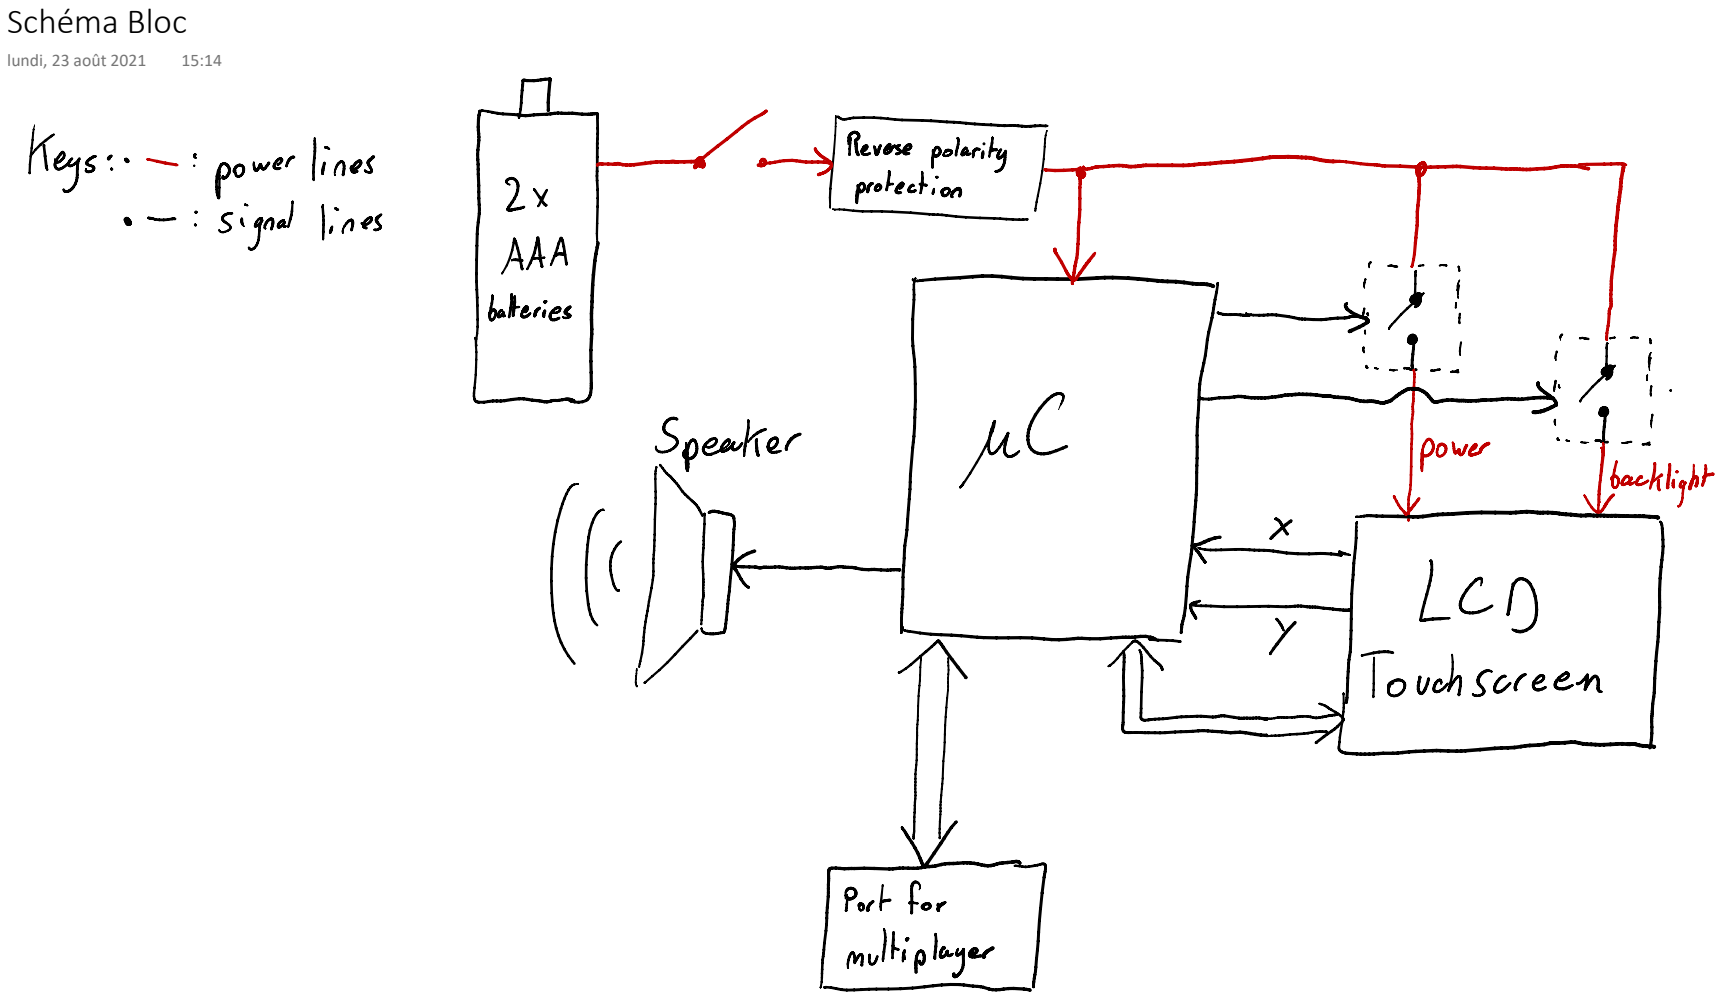
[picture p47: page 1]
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

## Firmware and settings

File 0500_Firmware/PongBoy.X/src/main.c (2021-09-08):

/*
 * File:   main.c
 * Author: Samy Francelet
 *
 * Created on 3. septembre 2021, 09:15
 */


#include <xc.h>

#include "pongboy/pongboy.h"

/**
 * Interruption routine
 * 
 * Timer0 is the XF timer
 * 
 * INT0 is the TouchScreen detection interrupt
 * 
 * @author Samy Francelet
 */
void __interrupt() isr(void) {
    // Interrupt on TIMER0
    if(TMR0IF == 1 && TMR0IE == 1)
    {
        TMR0IF = 0;         // reset interrupt flag
        TMR0 = 65535-1250;  // reload timer
        XF_decrementAndQueueTimers();
    }

    // Press on screen detected
    if (INT0IF == 1 && INT0IE == 1)
    {
        INT0IF = 0;
        if(INTEDG0 == 1) { // If on rising edge
            XF_pushEvent(TSC_evRelease, true);
        } else {
            XF_pushEvent(TSC_evPress, true);
        }
    }
}

/**
 * Initialise the PongBoy
 * and calls the event execution routine
 * 
 * @author Samy Francelet
 */
void main(void) {
    
    PongBoy_init();
    PongBoy_start();
    
    while(true) {
        PongBoy_execEvent();
    }
        
    return;
}

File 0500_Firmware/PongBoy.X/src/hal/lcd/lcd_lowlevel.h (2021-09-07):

#include <pic18.h>
#include <stdint.h>

#include "../../globaldefs.h"

#define NHD_24_CF   0
#define NHD_24_SF   1
#define NHD_18      2

/******************************************************************************/
/* Display selection                                                          */
/*                                                                            */
/*----------------------------------------------------------------------------*/
/* choose one of the three choices                                            */
/******************************************************************************/
#define  DISPLAY_NHD NHD_24_CF   // 2.4 " display (controller ST7789S)
//#define  DISPLAY_NHD NHD_24_SF    // 2.4 " display (controller ILI9163)
//#define  DISPLAY_NHD   18   // 1.8 " display (controller ILI9341)
/******************************************************************************/
/* Display direction choice                                                   */
/* todo - > vertical modes have not been tested !!!                           */
/*                                                                            */
/*----------------------------------------------------------------------------*/
/* choose one of the four choices                                             */
/* the normal direction means the connector is to the left (or to the top)    */
/******************************************************************************/
#define HORIZONTAL_NORMAL
//#define HORIZONTAL_INVERTED
//#define VERTICAL_NORMAL
//#define VERTICAL_INVERTED

#ifdef HORIZONTAL_NORMAL
#if (DISPLAY_NHD == NHD_24_SF)
#define   LCD_WIDTH  320
#define   LCD_HEIGHT 240
#define CMD_MEM_ACC_DATA     0b01101000
#define CMD_MEM_ACC_DATA_BMP 0b00101000
#endif
#if (DISPLAY_NHD == NHD_24_CF)
#define   LCD_WIDTH  320
#define   LCD_HEIGHT 240
#define CMD_MEM_ACC_DATA     0b01100000
#define CMD_MEM_ACC_DATA_BMP 0b00100000
#endif
#if (DISPLAY_NHD == NHD_18)
#define   LCD_WIDTH  160
#define   LCD_HEIGHT 128
#define CMD_MEM_ACC_DATA     0b01101000
#define CMD_MEM_ACC_DATA_BMP 0b00101000
#endif
#endif
#ifdef HORIZONTAL_INVERTED
#if (DISPLAY_NHD == NHD_24_SF)
#define   LCD_WIDTH  320
#define   LCD_HEIGHT 240
#define CMD_MEM_ACC_DATA     0b10101000
#define CMD_MEM_ACC_DATA_BMP 0b11101000
#endif
#if (DISPLAY_NHD == NHD_24_CF)
#define   LCD_WIDTH  320
#define   LCD_HEIGHT 240
#define CMD_MEM_ACC_DATA     0b10100000
#define CMD_MEM_ACC_DATA_BMP 0b11100000
#endif
#if (DISPLAY_NHD == NHD_18)
#define   LCD_WIDTH  160
#define   LCD_HEIGHT 128
#define CMD_MEM_ACC_DATA     0b10101000
#define CMD_MEM_ACC_DATA_BMP 0b11101000
#endif
#endif
#ifdef VERTICAL_NORMAL
#if (DISPLAY_NHD == NHD_24_SF)
#define   LCD_WIDTH  240
#define   LCD_HEIGHT 320
#define CMD_MEM_ACC_DATA     0b11001000
#define CMD_MEM_ACC_DATA_BMP 0b01001000
#endif
#if (DISPLAY_NHD == NHD_24_CF)
#define   LCD_WIDTH  240
#define   LCD_HEIGHT 320
#define CMD_MEM_ACC_DATA     0b11000000
#define CMD_MEM_ACC_DATA_BMP 0b01000000
#endif
#if (DISPLAY_NHD == NHD_18)
#define   LCD_WIDTH  128
#define   LCD_HEIGHT 160
#define CMD_MEM_ACC_DATA     0b11001000
#define CMD_MEM_ACC_DATA_BMP 0b01001000
#endif
#endif
#ifdef VERTICAL_INVERTED
#if (DISPLAY_NHD == NHD_24_SF)
#define   LCD_WIDTH  240
#define   LCD_HEIGHT 320
#define CMD_MEM_ACC_DATA     0b00001000
#define CMD_MEM_ACC_DATA_BMP 0b10001000
#endif
#if (DISPLAY_NHD == NHD_24_CF)
#define   LCD_WIDTH  240
#define   LCD_HEIGHT 320
#define CMD_MEM_ACC_DATA     0b00000000
#define CMD_MEM_ACC_DATA_BMP 0b10000000
#endif
#if (DISPLAY_NHD == NHD_18)
#define   LCD_WIDTH  128
#define   LCD_HEIGHT 160
#define CMD_MEM_ACC_DATA     0b00001000
#define CMD_MEM_ACC_DATA_BMP 0b10001000
#endif
#endif
/******************************************************************************/
/* constantes	for ILI9341 commands access                                     */
/******************************************************************************/
#if (DISPLAY_NHD == NHD_24_SF)

#define     CMD_SOFTRESET       0x01
#define     CMD_DISPOFF         0x28
#define     CMD_DISPON          0x29
#define     CMD_SLPOUT          0x11
#define     CMD_PWR_CTRL_A      0xCB
#define     CMD_PWR_CTRL_B      0xCF
#define     CMD_DRV_TIM_CTRL_A  0xE8
#define     CMD_DRV_TIM_CTRL_B  0xEA
#define     CMD_PWR_ON_SEQ_CTRL 0xED
#define     CMD_PUMP_RATIO_CTRL 0xF7
#define     CMD_INTERFACE_CTRL  0xF6
#define     CMD_PWR_CTRL_1      0xC0
#define     CMD_PWR_CTRL_2      0xC1
#define     CMD_VCOM_CTRL_1     0xC5
#define     CMD_VCOM_CTRL_2     0xC7
#define     CMD_MEM_ACC_CTRL    0x36
#define     CMD_FRAME_RATE_CTRL 0xB1
#define     CMD_DISP_FUNC_CTRL  0xB6
#define     CMD_PIXEL_FORMAT    0x3A
#define     GAMMA_CONTROL       0xF2
#define     GAMMA_CURVE         0x26
#define     COLUMN_ADDRESS      0x2A
#define     PAGE_ADDRESS        0x2B
#define     MEMORY_WRITE        0x2C
#define     MEMORY_READ         0x2E

/******************************************************************************/
/* constantes	for ST7789S commands access                                   */
/******************************************************************************/
#elif (DISPLAY_NHD == NHD_24_CF)

#define     CMD_SOFTRESET       0x01
#define     CMD_DISPOFF         0x28
#define     CMD_DISPON          0x29
#define     CMD_SLPOUT          0x11
#define     CMD_PWR_CTRL_A      0xCB
#define     CMD_PWR_CTRL_B      0xCF
#define     CMD_DRV_TIM_CTRL_A  0xE8
#define     CMD_DRV_TIM_CTRL_B  0xEA
#define     CMD_PWR_ON_SEQ_CTRL 0xED
#define     CMD_PUMP_RATIO_CTRL 0xF7
#define     CMD_INTERFACE_CTRL  0xF6
#define     CMD_PWR_CTRL_1      0xD0
#define     CMD_PWR_CTRL_2      0xC1
#define     CMD_VCOM_CTRL_1     0xC5
#define     CMD_VCOM_CTRL_2     0xC7
#define     CMD_MEM_ACC_CTRL    0x36
#define     CMD_FRAME_RATE_CTRL 0xC6
#define     CMD_DISP_FUNC_CTRL  0xB6
#define     CMD_PIXEL_FORMAT    0x3A
#define     GAMMA_CONTROL       0xF2
#define     GAMMA_CURVE         0x26
#define     COLUMN_ADDRESS      0x2A
#define     PAGE_ADDRESS        0x2B
#define     MEMORY_WRITE        0x2C
#define     MEMORY_READ         0x2E
#define     CMD_PORCH_SETTING   0xB2
#define     CMD_GATE_CTRL       0xB7
#define     CMD_VCOM_SETTING    0xBB
#define     CMD_LCM_CTRL        0xC0
#define     CMD_VDVVRH_EN       0xC2
#define     CMD_VRHS_SET        0XC3
#define     CMD_VDVS_SET        0xC4
#define     CMD_POSVOL_GAM_CTRL 0xE0
#define     CMD_NEGVOL_GAM_CTRL 0xE1
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

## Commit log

2021-08-24 Added diagrams
    [BoM.ods]
2021-08-24 Schematic V1.0
    [HESSO2L.PcbDoc, HESSO2L.PrjPcb, PongBoy.PrjPcb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]
2021-08-25 Schematic V1.2 + LCD fully rooted
    [PongBoy.PcbDoc, PongBoy.PrjPcb, PongBoy.SchDoc]
2021-08-26 PCB v1.0 finished and printed; BoM orderd
    [BoM.ods, PongBoy.PcbDoc, PongBoy.PrjPcb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]
2021-08-26 Fab files generated
    [BoM.ods, PongBoy.PrjPcb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]
2021-08-27 3D of the PCB exported
    [PongBoy.PrjPcb, PongBoy.step]
2021-08-29 First mechanical 3d drawings
    [A2_PongBoy.0004.iam, A2_PongBoy.iam, A2_TopCase.0007.ipt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]
2021-08-30 PongBoy case V1.0 finished and ready to print
    [A2_PongBoy.0004.iam, A2_PongBoy.0007.iam, A2_PongBoy.0007_1.iam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]
2021-08-30 Added xf files
    [P1_BottomCase.stl, P2_TopCase.stl, P3_BatteriesTray.stl]
2021-08-30 Correction of the PongBoy case : added a hole for the multiplayer connector
    [A2_PongBoy.0007.iam, A2_PongBoy.0007_1.iam, A2_PongBoy.0009.iam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]
2021-08-31 Corrected schematic revision and date
    [PongBoy.PrjPcb, PongBoy.SchDoc]
2021-08-31 PongBoy case V2.1 with pen finished and ready to 3d print
    [A2_PongBoy.0007.ipn, A2_PongBoy.0009.iam, A2_PongBoy.0009.idw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]
2021-09-01 Schematic and PCB update
    [PongBoy.PcbDoc, PongBoy.PrjPcb, PongBoy.SchDoc]
2021-09-07 Added the base for the menu with a button to start the game
    There is a bug with paddle collisions -> sometimes the ball gets in the paddle and bounce inside
    [display.c]
2021-09-07 MOSFETs soldered, code modified to turn on & off the screen
2021-09-07 InGame exit button added, and lowered the frequency of TSC measures to avoid flooding XF queue
    [display.c, tsc.c]
2021-09-09 Tried to change timer from 10ms to 1ms -> lags, need pro version of XC compiler
2021-09-12 J'ai envie de me défenestrer
    [Test_protocols.xlsx]
